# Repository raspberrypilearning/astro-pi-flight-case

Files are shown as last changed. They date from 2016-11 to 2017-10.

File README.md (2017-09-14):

# 3D-Printed Astro Pi flight case

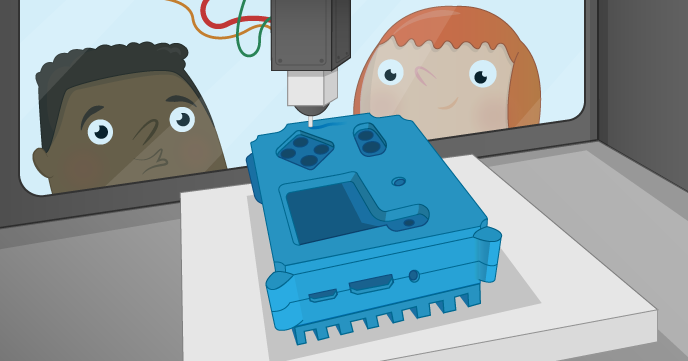
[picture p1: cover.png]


The Astro Pi flight case is one of the most desirable cases in the history of the Raspberry Pi. This resource shows you how to 3D print your own case and install the Astro Pi hardware inside it. You'll then have your very own Astro Pi flight unit, identical in almost every way to the ones on the International Space Station right now.

If you're participating in an Astro Pi competition, this is a great way to prototype and efficiently test your code in the same way as it would be used by the crew of the ISS.

## Licence

Unless otherwise specified, everything in this repository is covered by the following licence:



***3D-Printed Astro Pi Flight Case*** by the [Raspberry Pi Foundation](http://www.raspberrypi.org) is licenced under a [Creative Commons Attribution 4.0 International License](http://creativecommons.org/licenses/by-sa/4.0/).

Based on a work at https://github.com/raspberrypilearning/astro-pi-flight-case

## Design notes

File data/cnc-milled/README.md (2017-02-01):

# Flight CAD

5 axis CNC mill required.

These CAD files were used to manufacture the flight units flown to the ISS by the Astro Pi mission.

STEP, Parasoilid and STL formats with some PDF diagrams for convenience.

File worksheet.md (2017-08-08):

# 3D-printed Astro Pi flight case

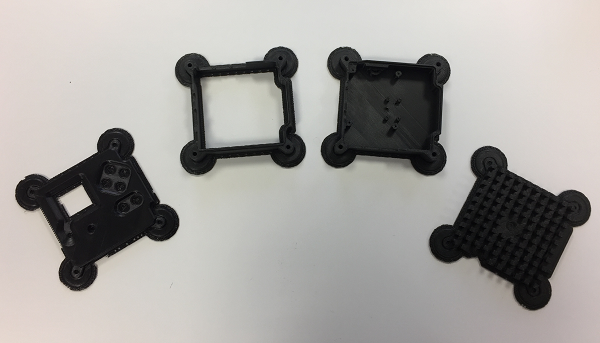
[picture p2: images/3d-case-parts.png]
3D prints of case


The Astro Pi flight case is one of the most desirable cases in the history of the Raspberry Pi. In this resource, you will learn how to 3D print your own case and install the Astro Pi hardware inside it. You'll then have your very own Astro Pi flight unit, identical in almost every way to the ones on the International Space Station right now.

If you're participating in an Astro Pi competition, this is a great way to prototype and efficiently test your code in the same way as it would be used by the crew of the ISS.

You can follow the video tutorial of this resource [here](https://www.youtube.com/embed/zmJOA6WzfZw).

<iframe width="560" height="315" src="https://www.youtube.com/embed/zmJOA6WzfZw" frameborder="0" allowfullscreen></iframe>

## Get access to a 3D printer

First and foremost, you'll need access to a 3D printer to do this. Many schools now have their own, but if your school doesn't then you may be able to find one at your local [hackspace](http://www.hackspace.org.uk/wiki/Main_Page). You can also find local 3D printing services through the [3D Hubs](https://www.3dhubs.com/) website.

## Get the 3D files

The 3D files are in [STL](https://en.wikipedia.org/wiki/STL_%28file_format%29) format, which is widely used in 3D printing all over the world. The software for your 3D printer will have no problem loading them. Import using metric millimetres (mm) and no scale adjustments will be required.

You can choose between printing using the standard STL file or the anti-warping STL file for each component. The anti-warping files add extra scaffolding around the case print to prevent the part becoming warped as it cools.

Print **one** file from each section:

**Part 1 - Heat sink**

* [Heat sink](https://github.com/raspberrypilearning/astro-pi-flight-case/raw/master/data/3d-printed/STL/Astro_Pi_Heat_Sink.stl) or [Anti-warp heat sink](https://github.com/raspberrypilearning/astro-pi-flight-case/raw/master/data/3d-printed/STL/anti-warping/Astro_Pi_Heat_Sink_warp.stl)

**Part 2 - Base**

* [Base for Model B+ or Pi 2](https://github.com/raspberrypilearning/astro-pi-flight-case/raw/master/data/3d-printed/STL/Astro_Pi_Base_Pi1_or_2.stl) or [Anti-warp base for Model B+ or Pi 2](https://github.com/raspberrypilearning/astro-pi-flight-case/raw/master/data/3d-printed/STL/anti-warping/Astro_Pi_Base_Pi1_or_2_warp.stl)
* [Base for Pi 3](https://github.com/raspberrypilearning/astro-pi-flight-case/raw/master/data/3d-printed/STL/Astro_Pi_Base_Pi3.stl) or [Anti-warp base for Pi 3](https://github.com/raspberrypilearning/astro-pi-flight-case/raw/master/data/3d-printed/STL/anti-warping/Astro_Pi_Base_Pi3_warp.stl)

**Part 3 - Middle**

* [Middle](https://github.com/raspberrypilearning/astro-pi-flight-case/raw/master/data/3d-printed/STL/Astro_Pi_Middle.stl) or [Anti-warp middle](https://github.com/raspberrypilearning/astro-pi-flight-case/raw/master/data/3d-printed/STL/anti-warping/Astro_Pi_Middle_warp.stl)

**Part 4 - Lid**

* [Lid 10mm](https://github.com/raspberrypilearning/astro-pi-flight-case/raw/master/data/3d-printed/STL/Astro_Pi_Lid_10mm_Buttons.stl) or [Anti-warp lid 10mm](https://github.com/raspberrypilearning/astro-pi-flight-case/raw/master/data/3d-printed/STL/anti-warping/Astro_Pi_Lid_10mm_Buttons_warp.stl) - 10mm holes, for use with the APEM buttons
* [Lid 7mm](https://github.com/raspberrypilearning/astro-pi-flight-case/raw/master/data/3d-printed/STL/Astro_Pi_Lid_7mm_Buttons.stl) or [Anti-warp lid 7mm](https://github.com/raspberrypilearning/astro-pi-flight-case/raw/master/data/3d-printed/STL/anti-warping/Astro_Pi_Lid_7mm_Buttons_warp.stl) - 7mm holes, for use with the buttons from the *components kit bag* in the ESA branded Astro Pi kits. Sold separately by [CPC](http://cpc.farnell.com/ucreate/uc-apk-comp1/astro-pi-component-kit-budget/dp/SC14158).
* [Lid 3mm](https://github.com/raspberrypilearning/astro-pi-flight-case/raw/master/data/3d-printed/STL/Astro_Pi_Lid_3mm_Pilot_Holes.stl) or [Anti-warp lid 3mm](https://github.com/raspberrypilearning/astro-pi-flight-case/raw/master/data/3d-printed/STL/anti-warping/Astro_Pi_Lid_3mm_Pilot_Holes_warp.stl) - 3mm pilot holes, for drilling to fit any button size

**Part 5 - Joystick cap**

Note that this joystick cap may need some slight adjustments due to the nozzle size and layer height of your printer. If you have difficulty with fitting it onto the stump of the Sense HAT joystick then try using a layer height of 0.1 mm as opposed to 0.15 mm.

* [Joystick](https://github.com/raspberrypilearning/astro-pi-flight-case/raw/master/data/3d-printed/STL/Astro_Pi_Joystick.stl)

The 3D files don't exactly match those used to make the aluminium flight cases on the International Space Station. They have been modified to make them compatible with 3D printers, so that most people who attempt this will achieve success without difficulty.

Most importantly, the case has been sliced into four parts. This has been done to minimise the amount of rafting and scaffolding that needs to be printed along with the model. It also reduces the amount of time you spend cleaning up the final prints.

## Safety first

**It is important that you observe the correct safety procedures specified in the data sheet for your specific 3D printer.**

Potential hazards include:

- Hot surfaces and thermoplastics (print head block and lamp)
- Ultraviolet radiation (lamp)
- High voltage (lamp connector, electric outlet)
- Moving parts (printing assembly)

## Print each part

The 3D printer we used for the black parts shown was an [Up Plus 2](https://www.3dhubs.com/3d-printers/up-plus-2), called the Afinia H480 in the US, using ABS filament. Because there are so many different types of 3D printer, we cannot possibly provide instructions for them all. We can only provide rough guidance here and you'll need to figure out the rest on your own.

Here are some top tips though:

- Spend some time making sure your printer is properly calibrated and tested
- [PLA](https://en.wikipedia.org/wiki/Polylactic_acid) is more reliable and nicer to print with than [ABS](https://en.wikipedia.org/wiki/Acrylonitrile_butadiene_styrene)
- A [Zebra](http://www.printinz.com/zebra-plates/) or [Buildtak](http://www.buildtak.eu/) plate provides a great surface to print on without any extra adhesive being required
- If your printer has a Z probe sensor, this will help compensate for the bed not being perfectly level; ensure it's working correctly if you have one

To get a nice finish we recommend you print on a high detail setting; this is usually a number specified in [microns](https://en.wikipedia.org/wiki/Micrometre) in the 3D printer software. The lower this number is, the more precise the model will be. Please also be aware that precise prints take longer and, for these models, each piece can take up to **four** hours to complete. Make sure you have enough filament.

The STL files should have the models like this by default, but please make sure you print in the orientations shown below in order to minimise scaffolding and rafting.

### Heat sink

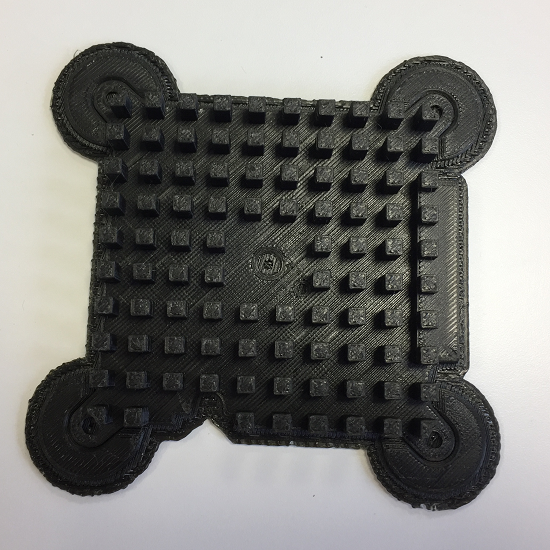
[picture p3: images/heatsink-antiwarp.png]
Anti warp heat sink raw print


### Base

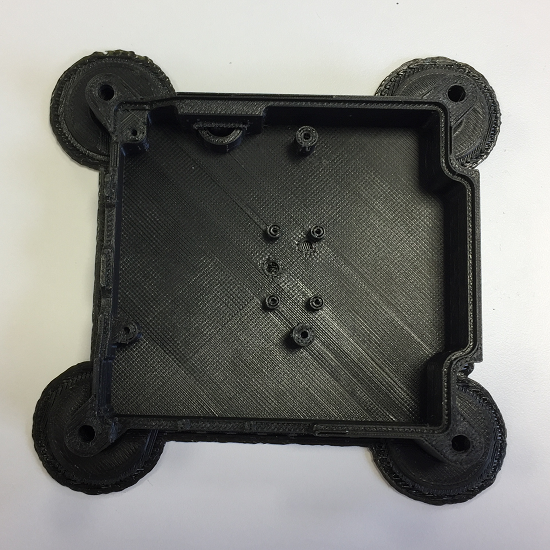
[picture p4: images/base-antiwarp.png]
Anti warp base raw print


### Middle

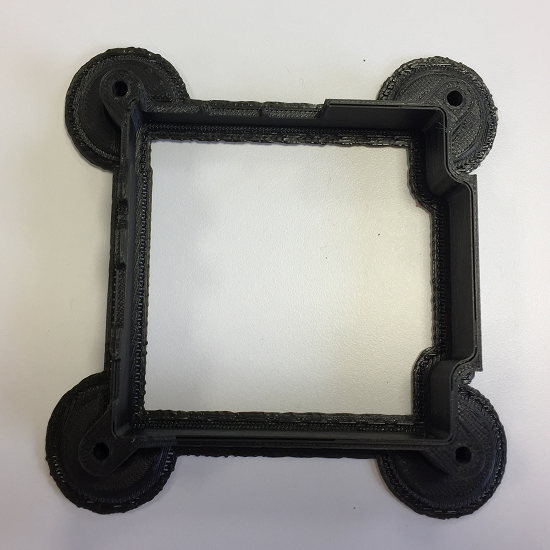
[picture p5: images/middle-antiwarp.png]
Anti warp middle raw print


### Lid

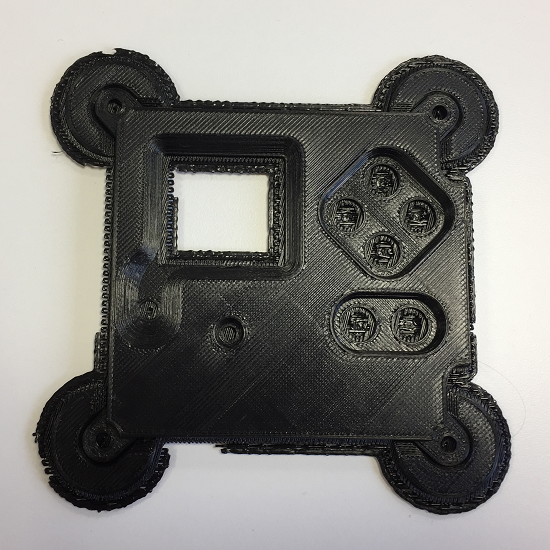
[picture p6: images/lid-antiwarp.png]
Anti warp lid raw print


## Remove the scaffolding

In order to keep the model structurally sound while printing, your 3D printer will create what's called scaffolding and rafting to prevent the hot thermoplastics from bending or sagging. Leave the print to cool right down to room temperature before you touch it.

### Heat sink

You should be able to remove the scaffolding on the heat sink using just your hands; this part may bend slightly, so don't be too rough while you are removing the unwanted material.

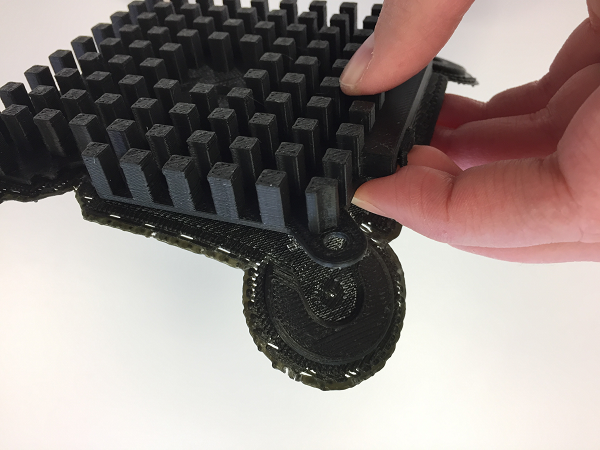
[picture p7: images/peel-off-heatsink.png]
Peel off the heat sink scaffolding


You may choose to not print this part because it's not essential to the rest of the case, and because it's made of plastic it **will not** work as a heat sink. We've included it, though, so that you can achieve the iconic look and feel of the Astro Pi flight case.

### Base

The base scaffolding should come away easily as with the heat sink.

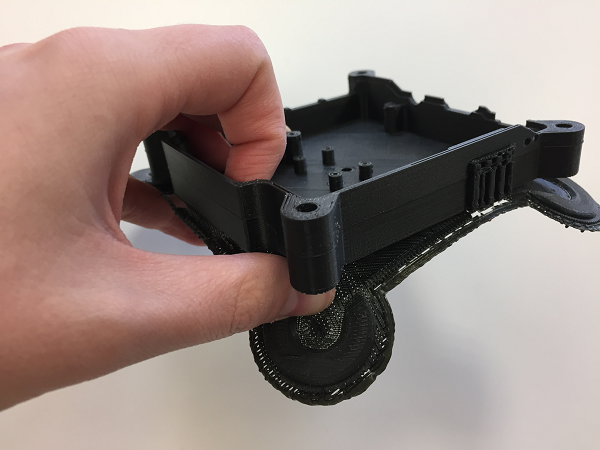
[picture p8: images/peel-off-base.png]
Peel off the base scaffolding


If the scaffolding breaks off unintentionally, carefully prise up the remaining scaffolding using a scalpel and then continue peeling it off with your fingers.

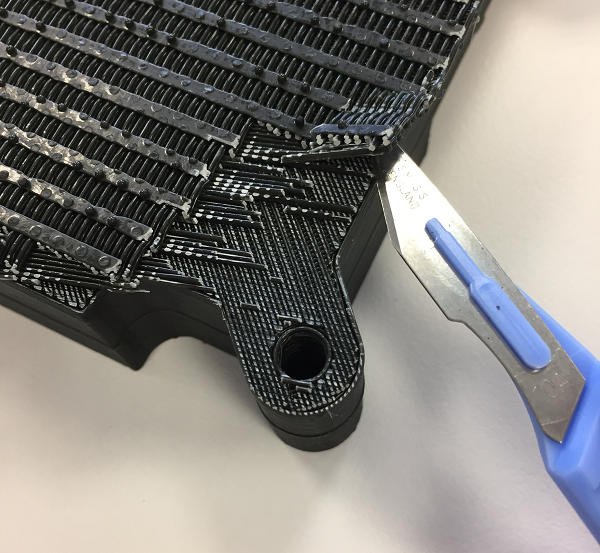
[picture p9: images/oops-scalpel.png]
If the scaffolding breaks


Don't worry if you scuff the surface with the scalpel as the rough side of the print will not be visible when the case is assembled.

Don't forget to clear the material around the SD card slot; this can easily be done with pliers.

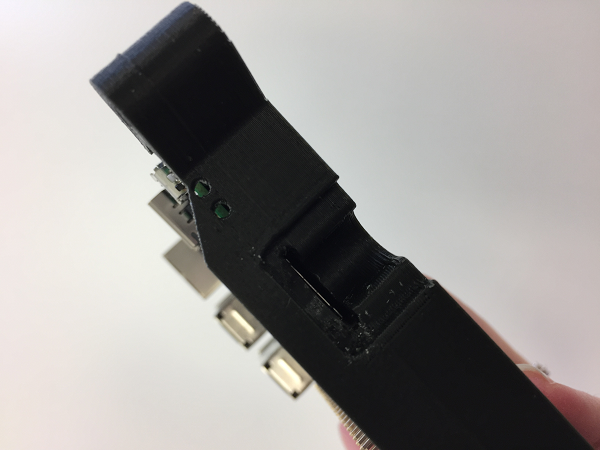
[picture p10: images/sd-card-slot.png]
Clear the SD card slot


### Middle

Again, the scaffolding should come away easily by peeling it with your fingers.

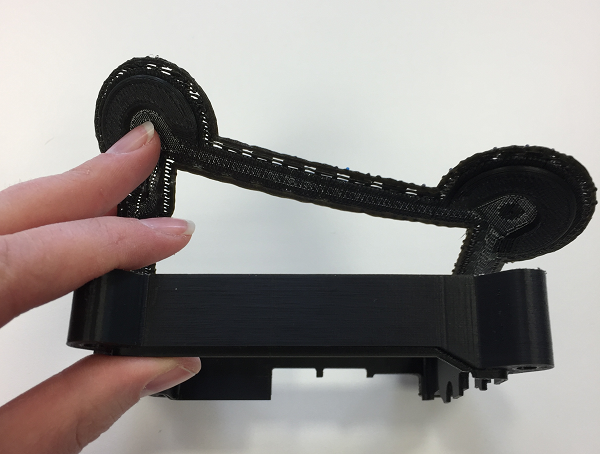
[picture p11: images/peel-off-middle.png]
Peel off the middle scaffolding


### Lid

Peel off the bottom layer of scaffolding as before.

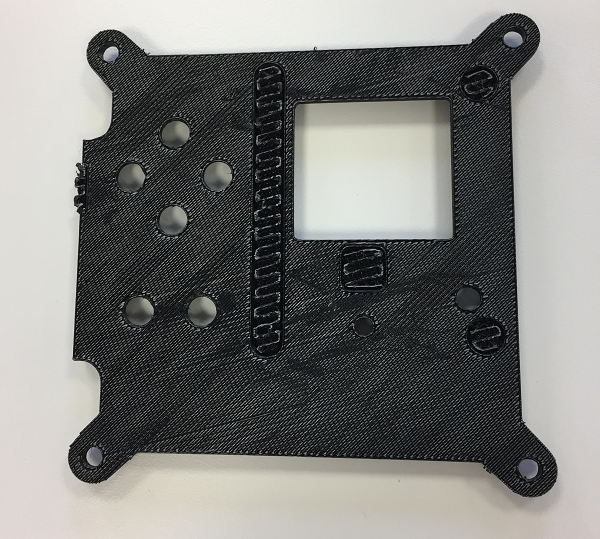
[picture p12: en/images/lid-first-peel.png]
When you first peel off the lid


However, there are a few sunken holes on the underside that must also be cleared of material. These are present to prevent the lid from striking the Raspberry Pi hardware when it is installed in the case. You'll need a scalpel or craft knife to dig into it.

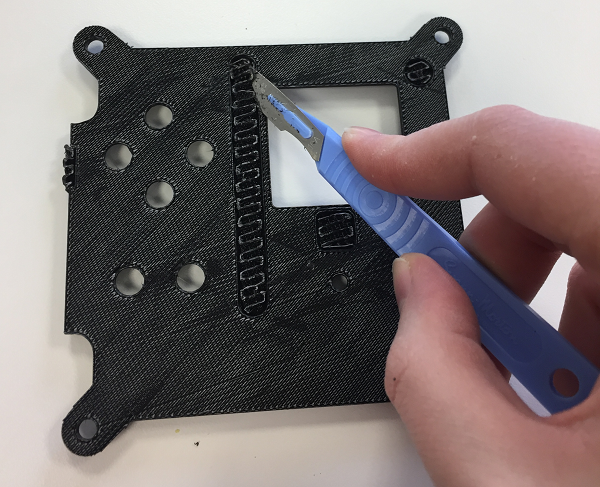
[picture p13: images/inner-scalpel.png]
Use a scalpel to lift the scaffold


Once you've managed to lift some of it, use a small pair of pliers to remove the rest of the material. The areas marked with a red star below need the same treatment.

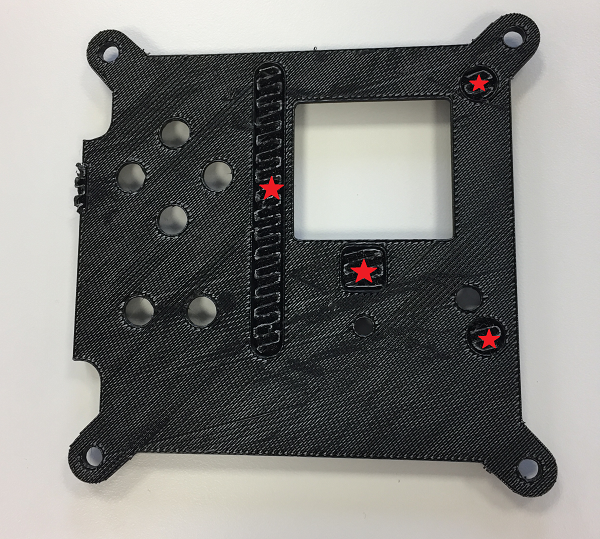
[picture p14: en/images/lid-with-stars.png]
Stars show which bits need to be removed


When you're done it should look like this:

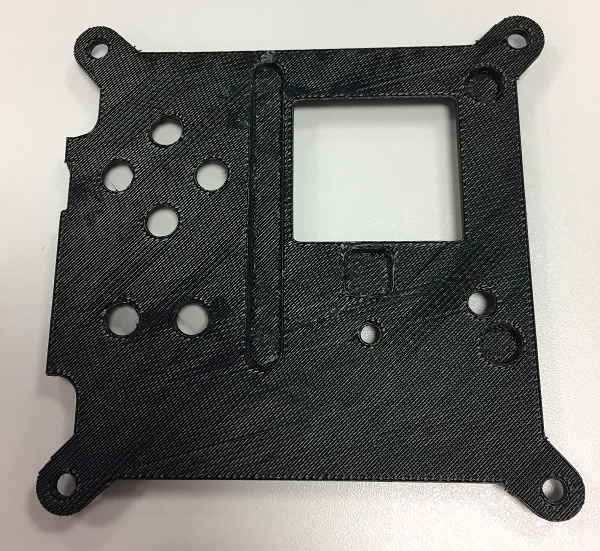
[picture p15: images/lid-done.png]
Cleaned up lid


## Do a fit check

Before proceeding, put all the pieces together to check that they fit correctly. The lipped edge between the base and middle pieces is of most concern to you here. The heat sink and lid just need to line up.

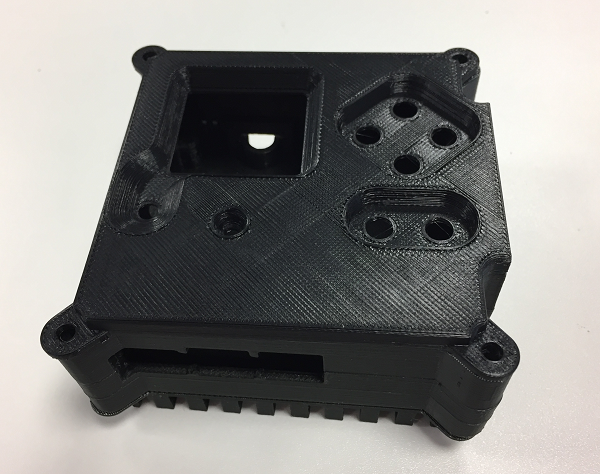
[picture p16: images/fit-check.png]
Fit the case together


Don't worry about any imperfections or residue from the scaffolding at this stage; you can tidy this up later with sandpaper.

## Checklist

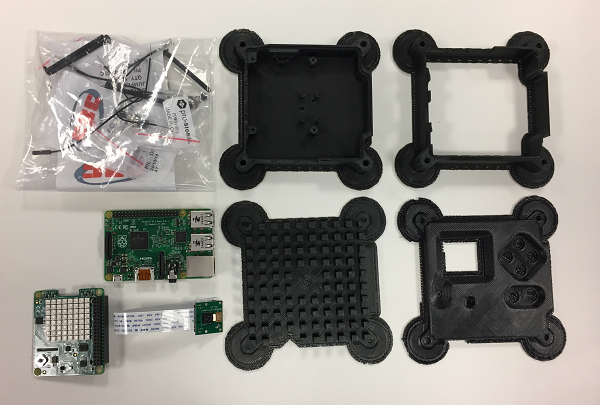
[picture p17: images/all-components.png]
All required components


Alongside your 3D-printed parts, check that you have all of the other parts required before you start:

Part|Quantity|Info|Purpose
---|---|---|---
Raspberry Pi|1|B+, Pi 2, or Pi 3|Main computer
Camera Module|1|Normal or Pi NoIR|Main camera
Sense HAT|1|&nbsp;|Main sensors

If you're planning to build a full Astro Pi flight unit, you can purchase a [kit containing the required components](http://cpc.farnell.com/ucreate/uc-apk-comp1/astro-pi-component-kit-budget/dp/SC14158) from CPC.

Part|Quantity|Info|Purpose
---|---|---|---
female-to-female jumper wires|10|Two each of red, yellow, blue, green, black|Connecting the buttons
Extended 26-way pin header|1|&nbsp;|Goes onto the GPIO pins to hold the Sense HAT at the correct height
Insulation boot|15|&nbsp;|Insulates button wiring
Friction fit crimp|15||Crimping wires together
M2 cross-head screw|4|Black 4 mm|Fixes Camera Module to base
M2.5 cross-head screw|4|Silver 6 mm|Fixes the top of the Sense HAT to the stand offs below
M2.5 washer|4|&nbsp;|Holds the Sense HAT at the correct height
M2.5 nut|4|&nbsp;|Holds the Sense HAT at the correct height
M4 hex nut|4|&nbsp;|Used in the corner bolt enclosures to hold the case together
M4 bolt|4|50 mm|Used in the corner bolt enclosures to hold the case together
M2.5 male-to-female stand off|4|11 mm|Holds the Sense HAT at the correct height
M2.5 male-to-female stand off|4|8 mm|Holds the Sense HAT at the correct height
Tactile push-buttons|6|&nbsp;|Function buttons
Length of black wire|1|&nbsp;|To cut up for push-button wiring

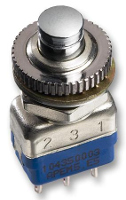
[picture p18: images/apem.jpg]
Astro Pi actual button


The kit already contains buttons, but if you want to buy the exact buttons used in the Astro Pi flight unit, the details are below. At about £9 each they are expensive, because they're designed to survive an enormous number of clicks before wearing out, which is necessary for a seven-year space mission.

- Manufacturer: APEM
- Manufacturer Part No: 104350003

You're also going to need the following tools:

- Small cross-head screwdriver
- Small pair of pliers
- Craft knife or scalpel
- Sandpaper
- Tape
- Wire strippers
- Wire cutters

## Continue to install the hardware

- [Install the hardware](worksheet2.md)

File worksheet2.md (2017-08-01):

# 3D printed Astro Pi flight case

- [Back to 3D printing and setup](worksheet.md)

When you're happy with the 3D-printed parts you can proceed with installing the hardware.

## Install the camera

Getting the camera into the case can be a little tricky but here is how we did it for the flight units. Firstly, lift the two tabs on either side of the Camera Module to disconnect the ribbon cable from the camera. Then fold the ribbon. These folds allow the camera cable to come up the side of the Raspberry Pi with enough flex to insert into the CSI camera port (see further down).

1. Lay the ribbon out with the writing face up and the visible connectors on the left. At 1cm along the ribbon, fold the ribbon downwards.

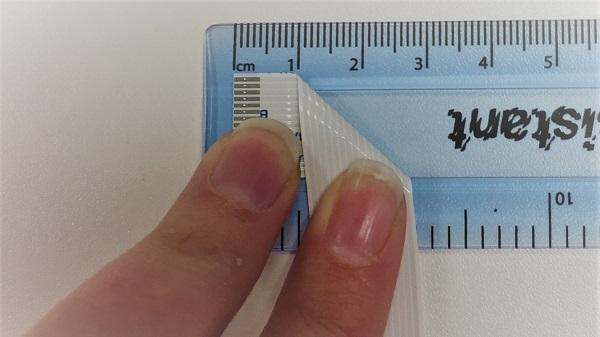
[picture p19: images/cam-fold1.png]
Fold down at 1cm
  

2. Now measure 4cm from the top of the ribbon and fold the ribbon to the right.

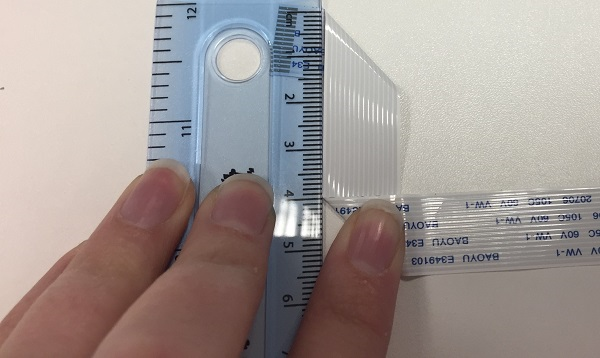
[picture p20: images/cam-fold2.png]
Fold 4cm right
  

3. Finally, measuring 4cm from the bottom-left corner, fold the ribbon upwards.

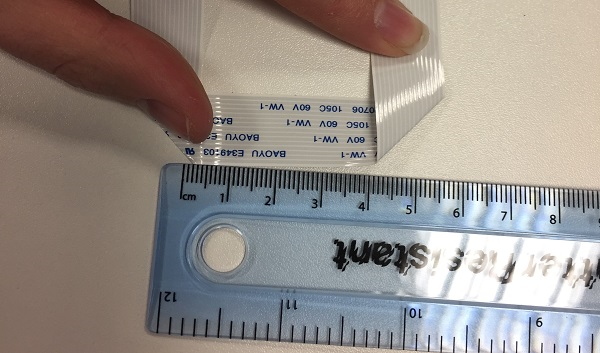
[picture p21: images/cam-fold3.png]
Fold 1cm
  

4. Tape the ribbon on the bottom to prevent it from unfurling. We have used kapton tape but any kind of tape will work fine.

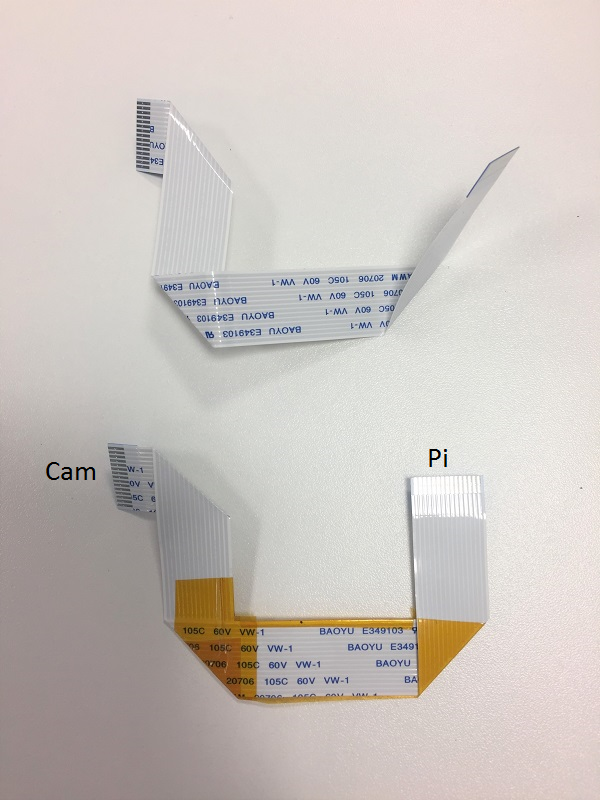
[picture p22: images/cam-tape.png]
Camera with tape
  

You don't need to get this perfect for it to work, but try to get it as close as possible.

Reconnect the **Cam** end of the ribbon cable to the Camera Module. Make sure that the tin connectors are facing the front and the blue tab is on the back.

Before proceeding, line the Camera Module up with the support pillar pilot holes and have a look through the aperture in the base to check the alignment of the lens. The lens block of the Camera Module is actually glued in position at the factory, and therefore its alignment can vary slightly from camera to camera. If you find you've got an alignment issue, you should be able to manipulate the lens block between finger and thumb before you install it into the case permanently.

When you're happy, use the small black M2 cross-head screws to install the Camera Module. The screws will cut their own thread in the support pillar pilot holes, but after a few turns you'll probably need a small screwdriver to continue.

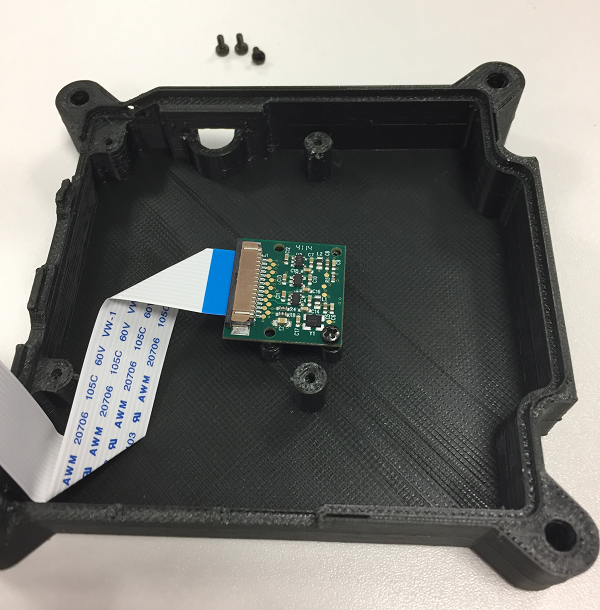
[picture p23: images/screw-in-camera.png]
Screw in the camera


Stop turning as soon as the head of the screw touches the Camera Module; if you tighten the screw too much it can cause the support pillar to split horizontally along the grain of the print. Furthermore, try to avoid removing and re-threading the screws as this will cut a new thread and, if done repeatedly, will erode the inside of the support pillar so that the screws will not hold.

## Install the Raspberry Pi

Firstly, ensure there's no residual scaffolding material around the SD card slot or LED holes that might prevent the Raspberry Pi from lining up with the mounting pillars. Once you're happy, line the Raspberry Pi up and do a fit check. Verify that it doesn't touch the Camera Module below it. Don't insert the camera ribbon cable just yet, as this will make the next job awkward.

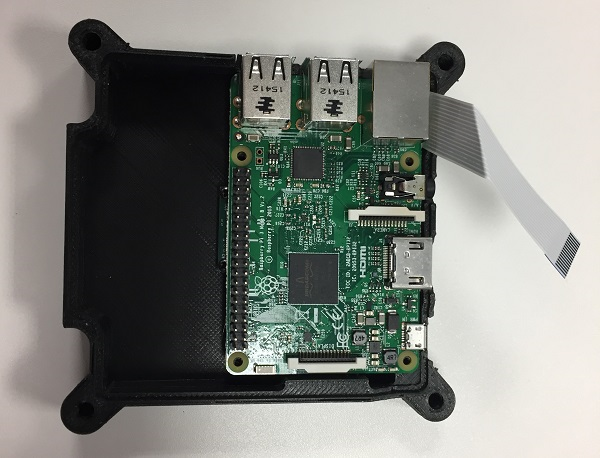
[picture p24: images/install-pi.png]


Next, screw the M2.5 11mm stand offs into each corner of the Pi. With some light finger pressure they will cut their own thread in the support pillar pilot holes. After a few turns you'll need to use a small pair of pliers to continue turning them. It's possible to get these to go in at a slight angle, which can lead to alignment issues with the Sense HAT later on, so do your best to make sure they go into the support pillars as straight as possible. Be careful while you do this and, again, stop turning as soon as the stand off touches the Raspberry Pi to avoid splitting the pillars horizontally along the grain of the print.

If you are having trouble screwing in the stand offs, screw one of the silver M2.5 cross head screws into the stand off, then use the screw head to screw the stand off into the case. Once the stand off is in place, don't forget to remove the screw.

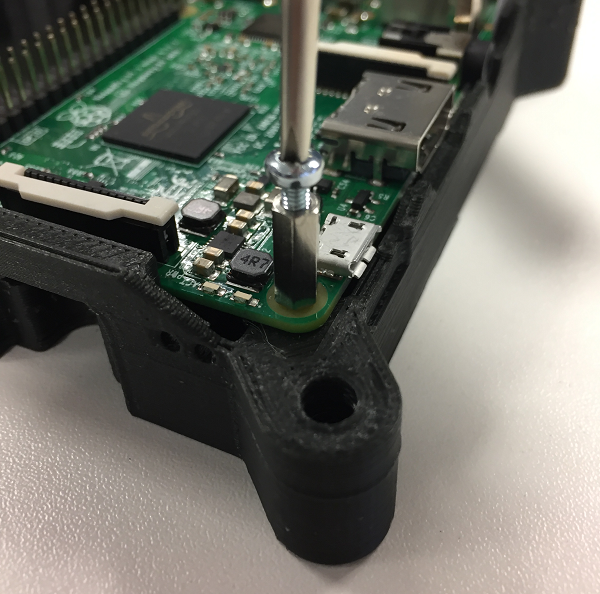
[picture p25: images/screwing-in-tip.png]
Use a screw to help you


You can now insert the camera ribbon cable into the CSI port of the Raspberry Pi. Try to make sure the tin connectors are all level to ensure a good connection.

## Install stand offs for the Sense HAT

This is where we're going to deviate from what's inside the Astro Pi flight unit. The flight units have another circuit board in between the Raspberry Pi and Sense HAT which holds a real-time clock, an oscillator crystal, and a backup battery. This RTC board also has some pins that the six push-buttons connect to. Unfortunately, this is not available to the public.

Our goal was to keep the 3D-printed flight case as faithful to the original as possible, so the decision was taken to not alter it to accommodate the absence of this board. It may be possible for us to release the Gerber files for it in the future so that people can make their own. We're going to use hex nuts of the same depth as the RTC board to compensate for its absence.

Add the extended 23-way pin header to the Raspberry Pi GPIO pins, at the furthest end from the USB ports. Then, take an 8mm M2.5 stand off and put a hex nut onto its thread before screwing it into the hole of the 11mm stand off, as shown below. Do the same for the remaining three stand offs.

Add standoffs

WARNING|&nbsp;
---|---
WiFi antenna|A note for Pi 3 users. Using a **metal** stand off next to the wireless antenna will degrade its performance and range. The advice is to either omit this stand off from your build or to use a nylon stand off and nylon screw instead.

Do not install the Sense HAT yet as it will get in the way when you connect the GPIO pins to the buttons.

## Install the push-buttons

This section assumes you are using the buttons from the Astro Pi [components kit](http://cpc.farnell.com/ucreate/uc-apk-comp1/astro-pi-component-kit-budget/dp/SC14158) from CPC. If you are using the APEM buttons or another type of button, these may differ in their installation.

Take a button, then unscrew and remove the nut. Sometimes the nut will get stuck on the button cap, but it should come off if you wiggle it.

Remove nut from button

Keeping the washer on the thread, insert the button from the underside of the lid. Then on the top side of the lid, put the nut back on and tighten it with your fingers. Check that the connectors are aligned horizontally on the underside before tightening fully.

Insert button and screw on nut

Do the same for the remaining buttons; when you are done it should look like this:

Finished front and back

If you are using the lid with the pilot holes then you'll need to check the datasheet for your chosen button type to find the **threaded bushing diameter**. Once you know this you can select a drill bit with this diameter, plus 1mm for clearance, and proceed to drill all six holes. We recommend using a vice or G clamp to hold the lid in place while you drill. You can then install the buttons in accordance with their requirements.

## Create the button wires

Firstly, you need to prepare the button wires to be able to attach them to the buttons. In the real flight unit, we soldered the button wires on to make them more reliable, but in the kit you will find jumper wires which will do the same job. The colour of the wires is not important as they are all exactly the same inside.

Take a coloured wire and, without cutting it, remove the black plastic sheath from **one** end. You can do this by pulling it off with wire cutters or by pulling up the small tab and removing it by hand. This exposes a pin connector. 

Pass a plastic insulation boot over the pin connector, narrow end first, and slide it out of the way down the wire. Then place the connector inside a crimp. 

Crimping the wire

Alternating the angle of your pliers, squash the crimp around the wire until there is no movement whatsoever of the pin connector within the crimp. Then slide the insulation boot back up over the wire and crimp. Repeat this six times with the other coloured jumper wires to create the wires we will connect to the six buttons.

Finished wire

To avoid having six more wires connected to the Raspberry Pi as ground wires, you will create a ground loop wire which connects to all of the buttons. This technique is also used in the real flight units. 

Take the piece of black wire, which should be approximately 50cm in length. Using a ruler and wire cutters, make five 10cm lengths. For each length, use wire strippers to expose at least 1cm of bare wire on both ends, then bend the wire into a U shape.

Black wire

Now take a black jumper wire and remove the black plastic sheath from one end to expose the connector, just as you did before. Hold the connector next to the end of one of your 10cm lengths of black wire, and pass both wires through the narrow end of an insulation boot. Insert both wires together into a crimp and tighten the crimp as before.

Black wire

Connect up the four remaining lengths of black wire to create a chain, crimping together a new wire with the exposed bare end of the previous wire. You will be left with one bare wire end as in the photograph below.

Black wire

For the final end, use pliers to fold the bare wire over to make it twice as thick before putting this wire alone inside a crimp and tightening up as before. You should end up with a chain containing six crimped ends and one black plastic jumper end.

## Connecting wires to the button terminals

First, you will connect your ground loop to the buttons. Starting with the top button, take the crimped wire end furthest from the black plastic jumper lead. Slide the insulation boot down, hold the crimp between finger and thumb and push it all the way onto the button terminal. Once the crimp is firmly in place, slide the insulation boot back up. Repeat to attach one of the black ground wire connections to each of the six buttons.

Ground wire connected to buttons

Now take the coloured wires you made earlier and connect one crimped end to the spare terminal of each button, using exactly the same method.

## Connecting the buttons to the Raspberry Pi

Fit the middle section of the Astro Pi case onto the base. You should do this now as the GPIO wires will prevent it from being fitted later.

Now you are going to wire the buttons to the free GPIO pins at the bottom of the header. Turn the Astro Pi case so that the Ethernet and USB ports are at the bottom, and the GPIO pins are on the right of the Raspberry Pi.

GPIO diagram

The pins marked in red are where you will wire up the buttons, with the bottom of the diagram being the pins closest to the USB ports. 

Look at the **underside** of the lid, with the buttons on the left and the display hole on the right. Connect the coloured wire from each button to the corresponding pin below:

- Top four buttons
    - Top: GPIO 26
    - Bottom: GPIO 13
    - Left: GPIO 19
    - Right: GPIO 20
- Bottom pair of buttons
    - Left: GPIO 21
    - Right: GPIO 16

Finally, connect the ground wire to either pin 34 or 39 (labelled Ground on the GPIO diagram). 

The lid will now be a bit awkward until we finish, but try to position it gently so it is not in the way.

The picture below is of one of the flight units that went into space. On the right, you can see the base of the RTC board with the connector pins for the buttons. If you look at the button contacts on the left, you'll see we used only one black ground wire that went from button to button.

Flight unit wiring

## Install the Sense HAT

Remove the GPIO connector that comes with the Sense HAT; wiggle it from side to side and it will come off without too much force. The Sense HAT can then be inserted onto the extended header. Note that these pins should not protrude through the top of the Sense HAT. If they do, then the height is not correct.

Remove the header from the Sense HAT

Finally, use the M2.5 cross-head screws to secure the Sense HAT to the stand offs below.

All buttons connected

## Assemble the case

Once you're happy that the internals of the case are complete, you can proceed to the final assembly stage. 

Take the lid and gently tuck the wires into the space on the right of the Pi as neatly as you can. Place the lid on top of the case and align the heat sink on the bottom.

Take the black M4 threaded bolts and insert one through each of the holes in the corners of the case. Inserting all four bolts at this stage will help to line everything up and make it easier to secure the case with the nuts.

Take one of the large hex nuts and with your index finger place it against the bottom of the bolt. Push the bolt back up so that the nut is then flush with the bottom of the case, and turn the head of the nut with your finger and thumb so that it catches the bolt thread. Tighten the nut with your fingers only. 

Hold the bolt

Once all four nuts are in place you can do a final tighten with a screwdriver.

Your Astro Pi is almost complete; the last thing to do is install your 3D-printed joystick cap by pressing it onto the joystick. For this, the real flight units use a TrackPoint cap from a Lenovo ThinkPad laptop!

Install joystick

## Test the buttons

Once you have assembled the Astro Pi, start it up with a monitor, keyboard, and mouse connected.

If you have the ESA-branded Astro Pi kit, when you turn the Astro Pi on, the rainbow pattern on the LED matrix should disappear after a few seconds and the push-buttons should now type letters. You can test this in the terminal by running the test program at the bottom of this section.

If you do not have the ESA-branded Astro Pi kit, when you turn the Astro Pi on, the rainbow pattern on the LED matrix will remain and the buttons will not work yet.

You will need to download some files and change a few configuration settings, so make sure your Astro Pi is online. Firstly, download the Device Tree overlay that maps the push-buttons to the corresponding keyboard keys. 

Open a terminal window and enter these commands:

```bash
cd /boot/overlays
sudo wget https://github.com/raspberrypilearning/astro-pi-flight-case/raw/master/data/dtb/astropi-keys.dtbo --no-check-certificate
```

Type `ls` and check that the file `astropi-keys.dtbo` is now showing in the list of files.

Next, we need to configure `config.txt` to load this overlay:

```bash
sudo nano /boot/config.txt
```

Go to the bottom of the file and enter the two lines below:

```bash
dtoverlay=rpi-sense
dtoverlay=astropi-keys
```

Press `Ctrl` + `O` then `Enter` to save, followed by `Ctrl` + `X` to quit.

Now reboot the Astro Pi.

```bash
sudo reboot
```

Now let's download and run a Python test program to check everything is working. The test code uses [Pygame](http://pygame.org/wiki/tutorials), so please do this on a directly connected monitor. It will not work via remote access. Open a terminal window and enter these commands:

```bash
cd ~
wget https://github.com/raspberrypilearning/astro-pi-flight-case/raw/master/data/test_code/pygame_test.py --no-check-certificate
chmod +x pygame_test.py
./pygame_test.py
```

Wiggle the joystick and press all push-buttons. If everything is working, the joystick should give a direction indication and the buttons will show the corresponding letter on the LED matrix. Press `Escape` to exit.

## What next?

We've deliberately not shown a really polished gorgeous case, because we're hoping you'll go the extra mile and blow our socks off. Please show us your cases by tweeting pictures of them to [@astro_pi](https://twitter.com/astro_pi) and [@raspberry_pi](https://twitter.com/Raspberry_Pi)!

Here are some further ideas for customising your case:

- Use metallic grey spray paint
- Use sandpaper to create the matt finish that the bead-blasted aluminium flight cases have
- Engrave decals into the case
- Use different colours of filament for each part

The STL files are released under the Creative Commons attribution [licence](http://creativecommons.org/licenses/by-sa/4.0/) so you are welcome to modify them. Please note that GitHub has a great [STL viewer](https://github.com/blog/1465-stl-file-viewing) as well as a [3D file diff](https://github.com/blog/1633-3d-file-diffs), which could be useful for tracking your changes.

By far the greatest benefit of owning a replica Astro Pi flight unit is the ability to prototype and test code that could be run on the International Space Station. Head over to the [Astro Pi website](https://astro-pi.org/) now to get involved!

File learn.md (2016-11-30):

By following this resource you will learn:

- How to 3D print the Astro Pi flight case
- How to correctly install the Astro Pi hardware inside the case
- What fixtures and fittings you need to accomplish this

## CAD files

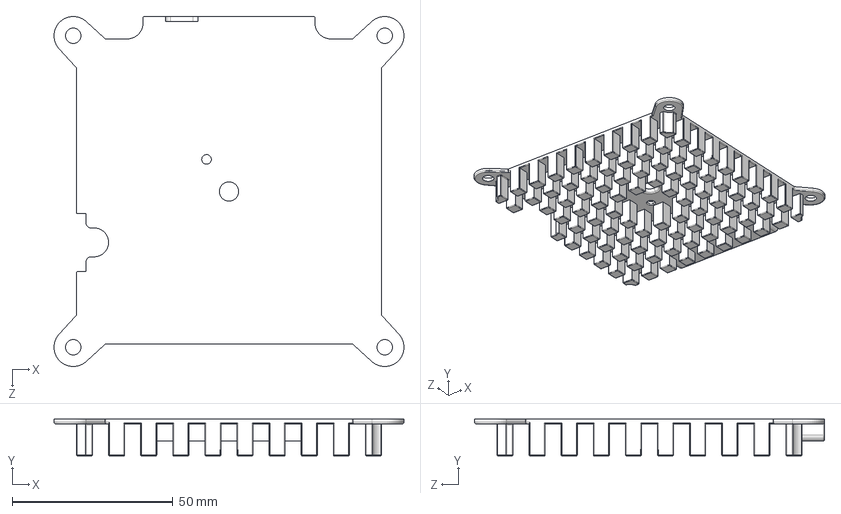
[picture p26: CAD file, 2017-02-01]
data/3d-printed/STEP/Astro_Pi_2.0_Enclosure_3D_PRINT_SECTION_1 V1.STEP
109.0 x 11.5 x 109.0 mm

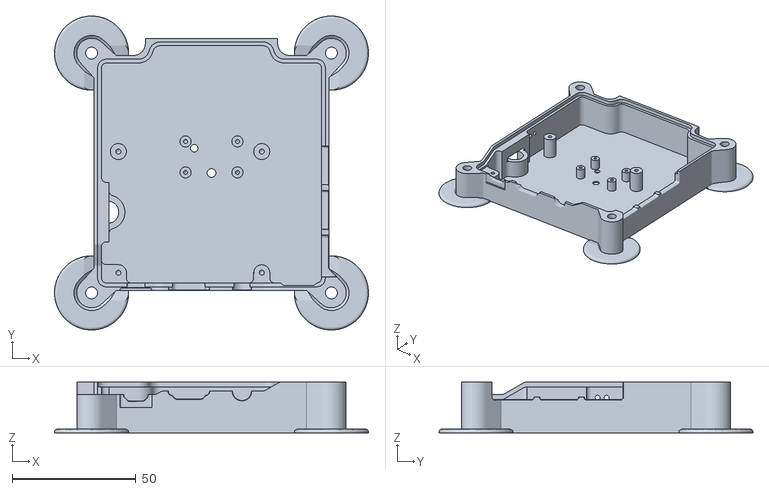
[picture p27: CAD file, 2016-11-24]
data/3d-printed/STL/anti-warping/Astro_Pi_Base_Pi1_or_2_warp.stl
127.0 x 127.0 x 20.5

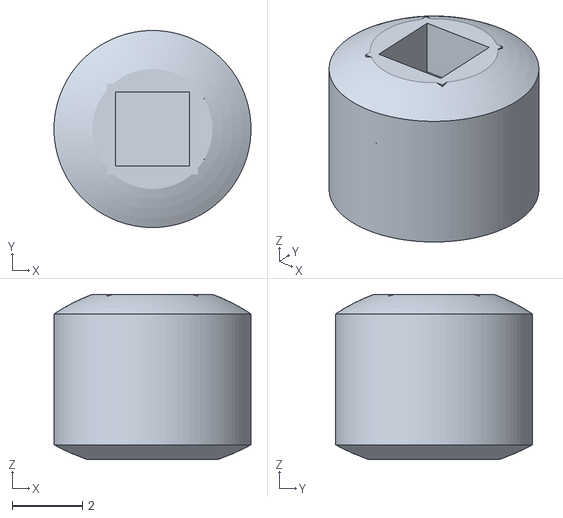
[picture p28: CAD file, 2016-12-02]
data/3d-printed/STL/Astro_Pi_Joystick.stl
5.60 x 5.60 x 4.70

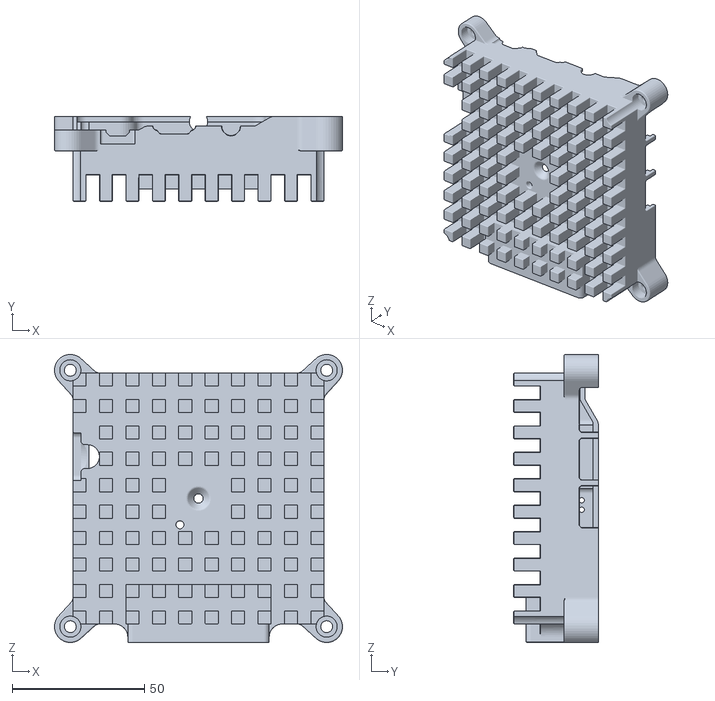
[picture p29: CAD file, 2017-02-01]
data/cnc-milled/STL/Astro_Pi_Enclosure_Body_EXPORTED_STL_050116.STL
109.0 x 32.0 x 109.0

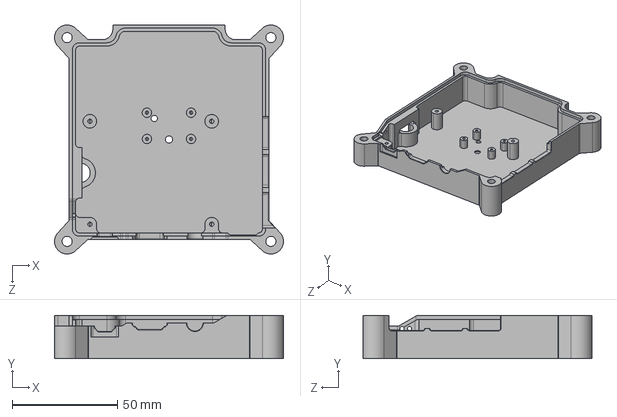
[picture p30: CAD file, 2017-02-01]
data/3d-printed/STEP/Astro_Pi_2.0_Enclosure_3D_PRINT_SECTION_2 V1a.STEP
109.0 x 20.5 x 109.0 mm

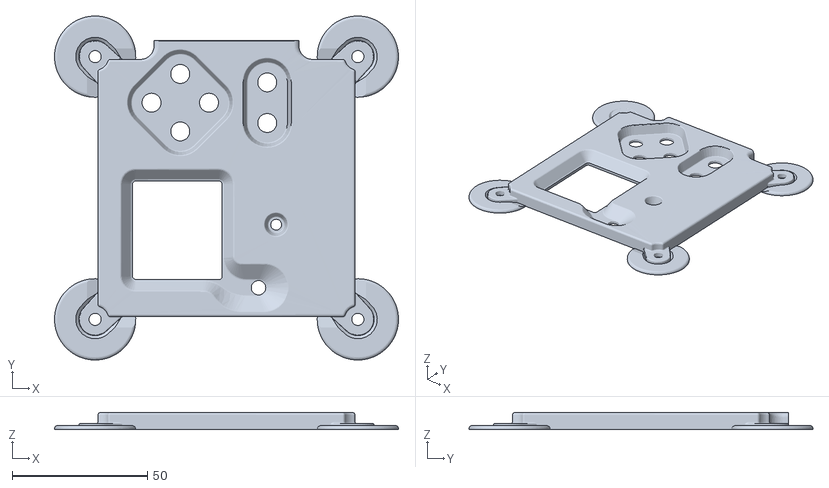
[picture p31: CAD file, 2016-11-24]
data/3d-printed/STL/anti-warping/Astro_Pi_Lid_7mm_Buttons_warp.stl
127.0 x 127.0 x 6.30

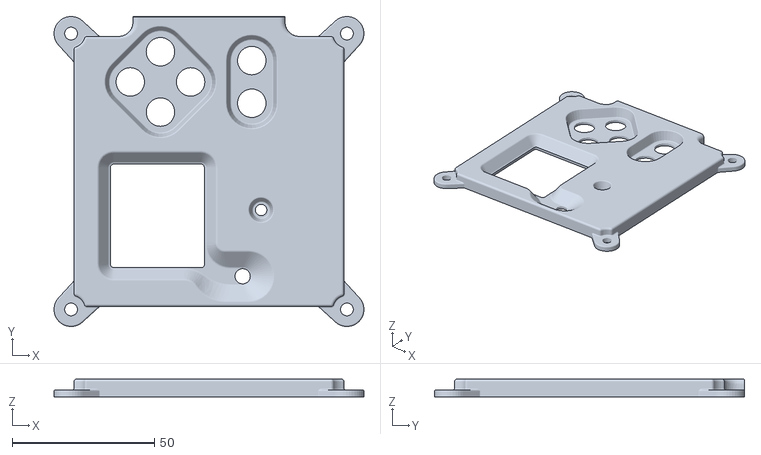
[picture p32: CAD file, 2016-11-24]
data/3d-printed/STL/Astro_Pi_Lid_10mm_Buttons.stl
109.0 x 109.0 x 6.30

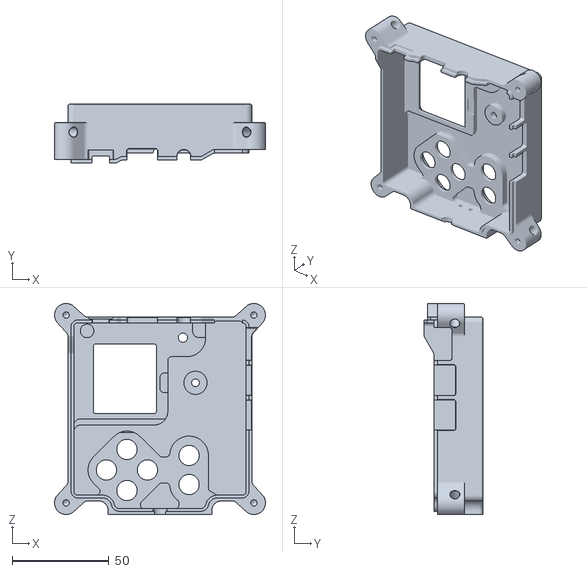
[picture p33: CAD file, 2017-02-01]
data/cnc-milled/STL/Astro_Pi_Enclosure_Lid_EXPORTED_STL_050116a.STL
109.0 x 30.4 x 109.0

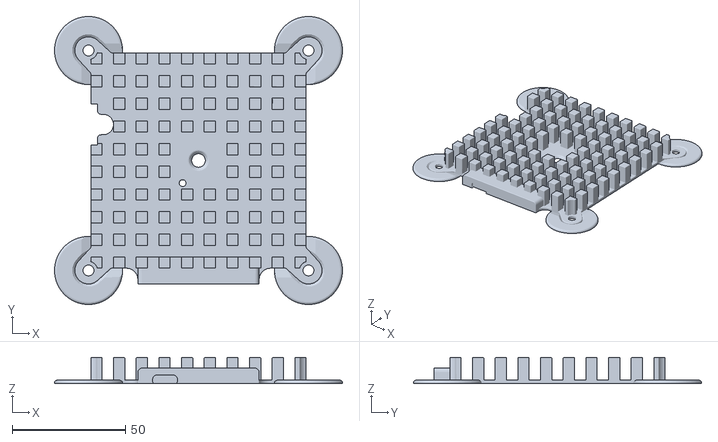
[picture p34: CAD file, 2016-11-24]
data/3d-printed/STL/anti-warping/Astro_Pi_Heat_Sink_warp.stl
127.0 x 127.0 x 11.5

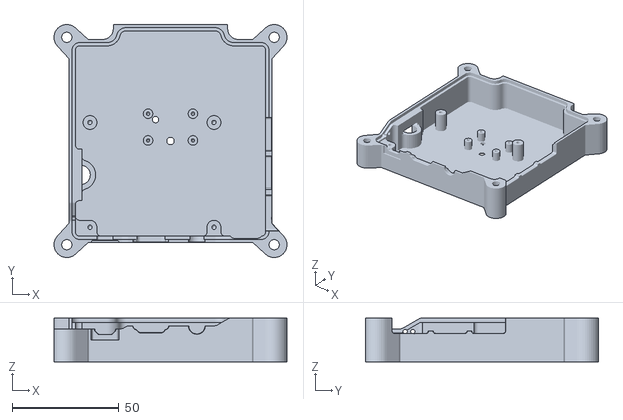
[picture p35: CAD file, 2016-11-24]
data/3d-printed/STL/Astro_Pi_Base_Pi3.stl
109.0 x 109.0 x 20.5

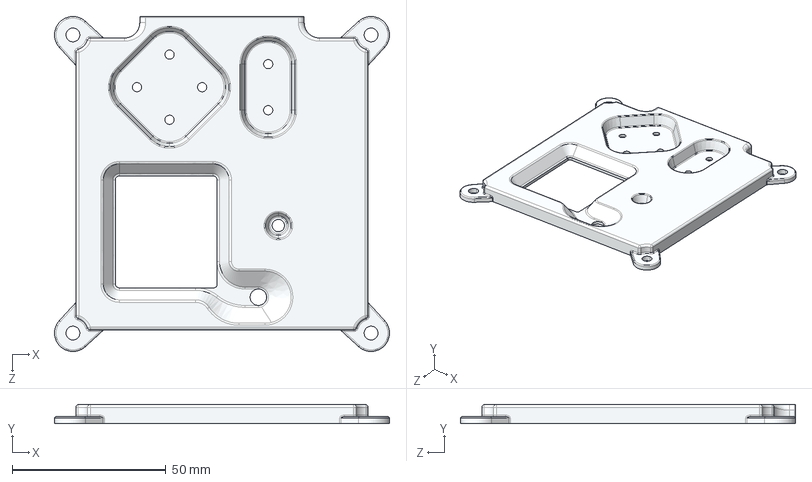
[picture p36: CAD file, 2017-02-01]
data/3d-printed/STEP/Astro_Pi_2.0_Enclosure_3D_PRINT_SECTION_4 V1a.STEP
109.0 x 6.30 x 109.0 mm

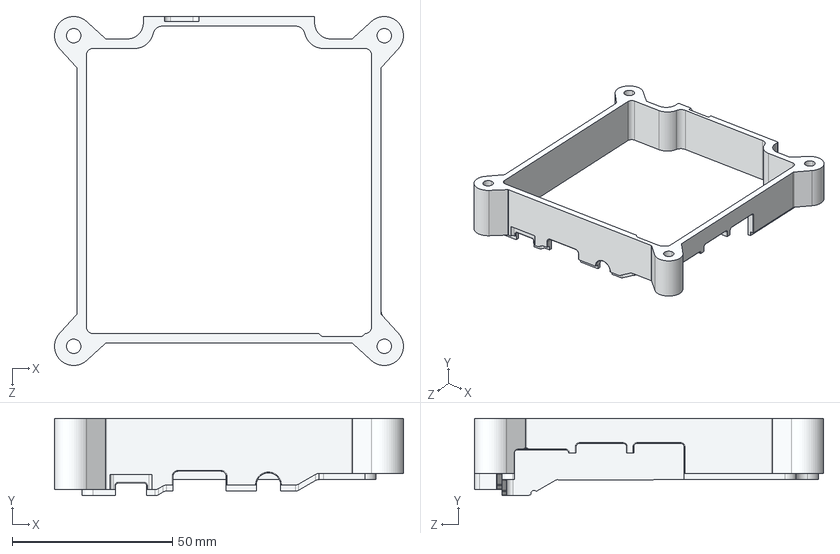
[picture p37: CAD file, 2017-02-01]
data/3d-printed/STEP/Astro_Pi_2.0_Enclosure_3D_PRINT_SECTION_3 V1.STEP
109.0 x 24.1 x 109.0 mm

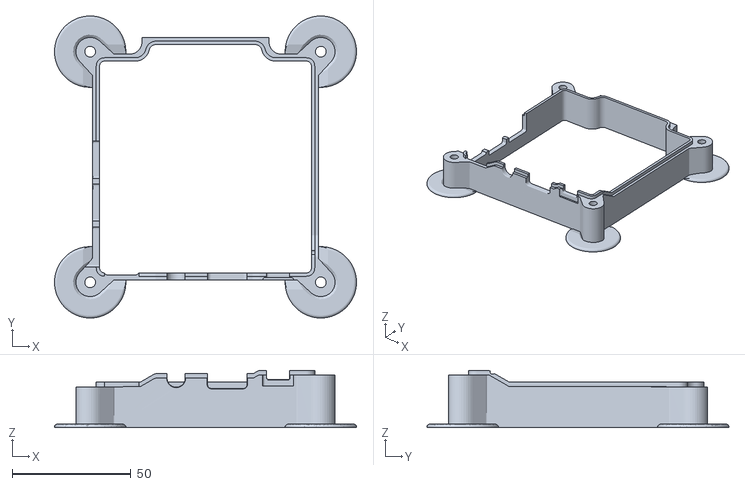
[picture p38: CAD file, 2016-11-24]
data/3d-printed/STL/anti-warping/Astro_Pi_Middle_warp.stl
127.0 x 127.0 x 24.1

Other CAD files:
data/3d-printed/STEP/Astro_Pi_2.0_Enclosure_3D_PRINT_SECTION_4 V1b.STEP
data/3d-printed/STL/anti-warping/Astro_Pi_Base_Pi3_warp.stl
data/3d-printed/STL/Astro_Pi_Lid_7mm_Buttons.stl
data/3d-printed/STL/Astro_Pi_Lid_3mm_Pilot_Holes.stl
data/3d-printed/STEP/Astro_Pi_2.0_Enclosure_3D_PRINT_SECTION_4 V1c.STEP
data/3d-printed/STEP/Astro_Pi_2.0_Enclosure_3D_PRINT_SECTION_2 V1b.STEP
data/3d-printed/STL/Astro_Pi_Base_Pi1_or_2.stl
data/3d-printed/STL/Astro_Pi_Heat_Sink.stl
data/3d-printed/STL/Astro_Pi_Middle.stl
data/3d-printed/STL/anti-warping/Astro_Pi_Lid_10mm_Buttons_warp.stl
data/3d-printed/STL/anti-warping/Astro_Pi_Lid_3mm_Pilot_Holes_warp.stl
data/3d-printed/x_t/Astro_Pi_2.0_Enclosure_3D_PRINT_SECTION_1 V1.x_t
data/3d-printed/x_t/Astro_Pi_2.0_Enclosure_3D_PRINT_SECTION_2 V1a.x_t
data/3d-printed/x_t/Astro_Pi_2.0_Enclosure_3D_PRINT_SECTION_2 V1b.x_t
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

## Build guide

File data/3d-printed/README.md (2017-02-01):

# 3D Printer Files

The files here are intended to accompany this educational [resource](https://www.raspberrypi.org/learning/astro-pi-flight-case/).

Assembly video instructions [here](https://www.youtube.com/watch?v=kY1db5cec64).

STEP and Parasoild formats also provided for you to modify the files further yourself.

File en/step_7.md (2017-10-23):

## Parts checklist

Alongside your 3D-printed parts, check that you have all of the other parts required before you start:

All required components

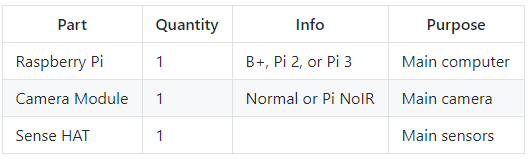
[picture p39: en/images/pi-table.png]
Pi requirements


If you're planning to build a full Astro Pi flight unit, you can purchase a [kit containing the required components](http://cpc.farnell.com/ucreate/uc-apk-comp1/astro-pi-component-kit-budget/dp/SC14158) from CPC.

--- collapse ---
---
title: Full list of kit parts
---
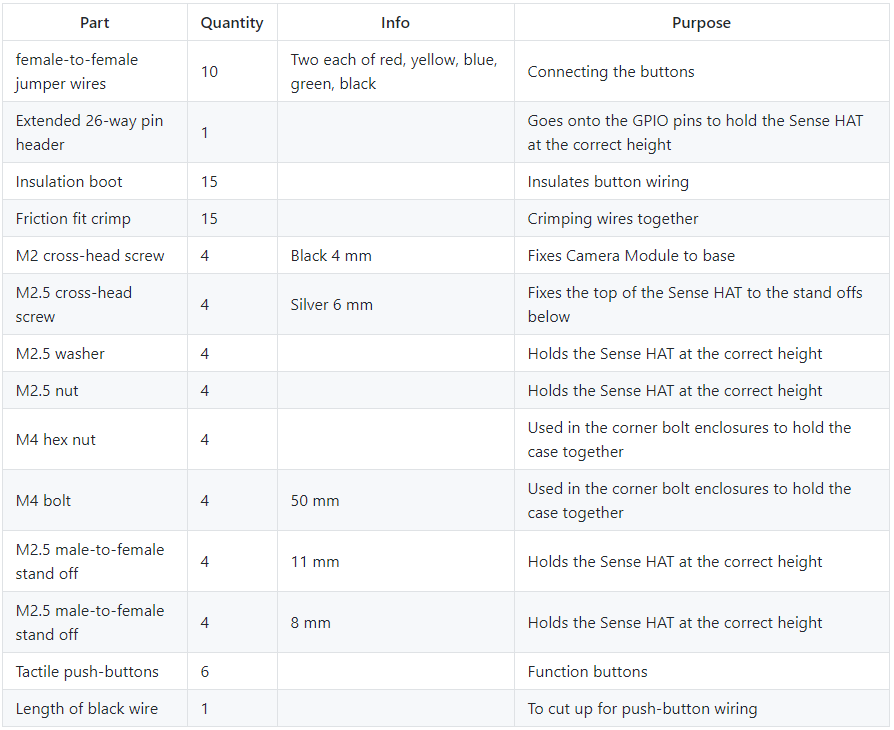
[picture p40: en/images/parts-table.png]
Parts table


--- /collapse ---

Astro Pi actual button

The kit already contains buttons, but if you want to buy the exact buttons used in the Astro Pi flight unit, the details are below. At a price of £9 each, they are expensive — that's because they're designed to survive an enormous number of clicks before wearing out, a feature which is necessary for a seven-year space mission.

- Manufacturer: APEM
- Manufacturer Part No: 104350003

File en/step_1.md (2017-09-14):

## Introduction
The Astro Pi flight case is one of the most sought-after cases in the history of the Raspberry Pi. In this resource, you will learn how to 3D print your own case and install the Astro Pi hardware inside it. You'll then have your very own Astro Pi flight unit, identical in almost every way to the ones on the International Space Station right now.

3D prints of case

If you're participating in an Astro Pi competition, this is a great way to prototype and efficiently test your code in the same way as it would be used by the crew of the ISS.

You can follow the video tutorial of this resource [here](https://www.youtube.com/embed/zmJOA6WzfZw){:target="_blank"}.

<iframe width="560" height="315" src="https://www.youtube.com/embed/zmJOA6WzfZw" frameborder="0" allowfullscreen></iframe>

### What you will make

Here is an example of how your finished 3D-printed Astro Pi flight case might look:

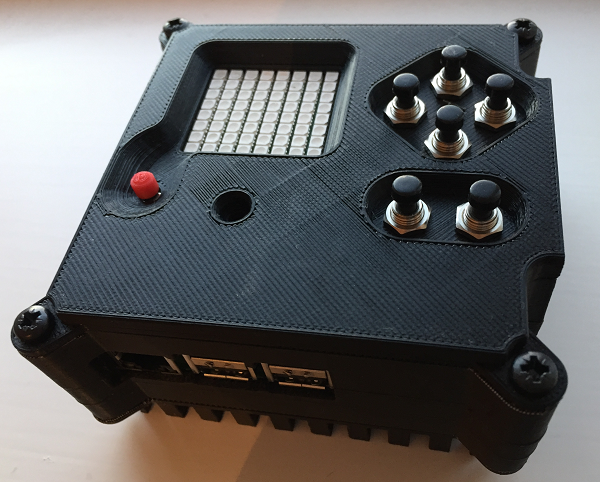
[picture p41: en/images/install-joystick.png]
Finished case


### What you will learn
By following this resource you will learn:

- How to 3D print the Astro Pi flight case
- What fixtures and fittings you need to install the Astro Pi hardware
- How to correctly install the Astro Pi hardware inside the case

This project covers elements from the following strands of the [Raspberry Pi Digital Making Curriculum](http://rpf.io/curriculum){:target="_blank"}:

+ [Use manufacturing techniques and tools to create a completed product](https://curriculum.raspberrypi.org/manufacture/developer/){:target="_blank"}

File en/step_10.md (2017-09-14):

## Install stand-offs for the Sense HAT

This is where we're going to deviate from what's inside the Astro Pi flight unit. The flight units have another circuit board in between the Raspberry Pi and Sense HAT which holds a real-time clock, an oscillator crystal, and a backup battery. This RTC board also has some pins with six connected push-buttons. Unfortunately, the board is not available to the public.

Our goal was to keep the 3D-printed flight case as faithful to the original as possible, so the decision was taken to not alter it to accommodate the absence of this board. It may be possible for us to release the Gerber files for it in the future, so that people can make their own. We're going to use hex nuts of the same depth as the RTC board to compensate for its absence.

+ Add the extended 23-way pin header to the Raspberry Pi GPIO pins, at the end away from the USB ports.

+ Then, take an 8mm M2.5 stand-off and put a hex nut onto its thread before screwing it into the hole of the 11mm stand-off, as shown below. Do the same for the remaining three stand-offs.

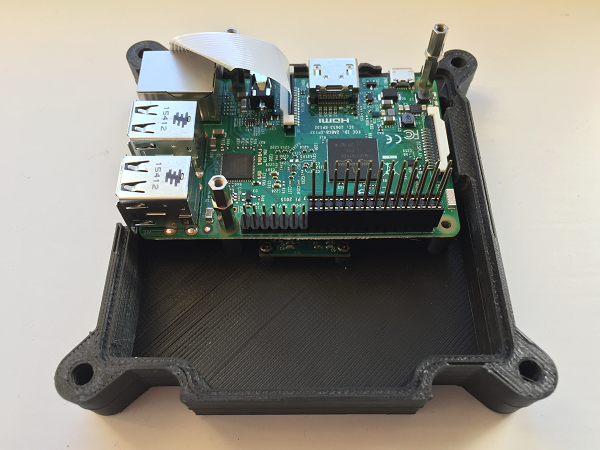
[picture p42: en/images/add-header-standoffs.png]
Add standoffs


WARNING|&nbsp;
---|---
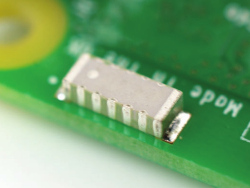
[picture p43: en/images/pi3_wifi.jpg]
WiFi antenna
|A note for Pi 3 users. Using a **metal** stand-off next to the wireless antenna will degrade its performance and range. The advice is to either omit this stand-off from your build, or to use a nylon stand-off and nylon screw instead.

+ Do not install the Sense HAT yet, as it will get in the way when you connect the GPIO pins to the buttons.

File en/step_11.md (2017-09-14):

## Install the push-buttons

This section assumes you are using the buttons from the Astro Pi [components kit](http://cpc.farnell.com/ucreate/uc-apk-comp1/astro-pi-component-kit-budget/dp/SC14158){:target="_blank"} from CPC. If you are using APEM buttons or another type of button, their installation might be different.

+ Take a button, then unscrew and remove the nut. Sometimes the nut will get stuck on the button cap, but it should come off if you wiggle it.

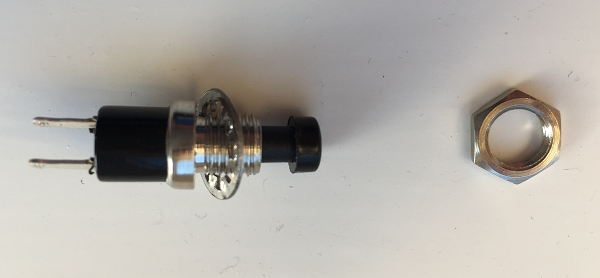
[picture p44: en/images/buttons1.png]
Remove nut from button


+ Keeping the washer on the thread, insert the button from the underside of the lid.

+ Then on the top side of the lid, put the nut back on and tighten it with your fingers. Check that the connectors are aligned horizontally on the underside before tightening fully.

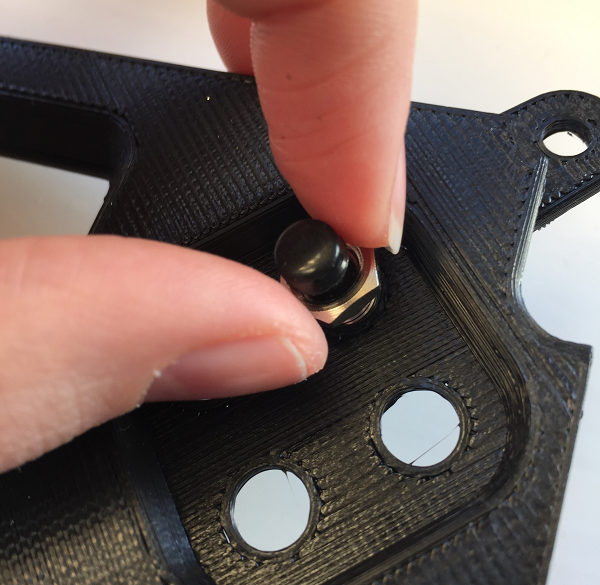
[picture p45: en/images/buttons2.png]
Insert button and screw on nut


+ Do the same for the remaining buttons; when you are done it should look like this:

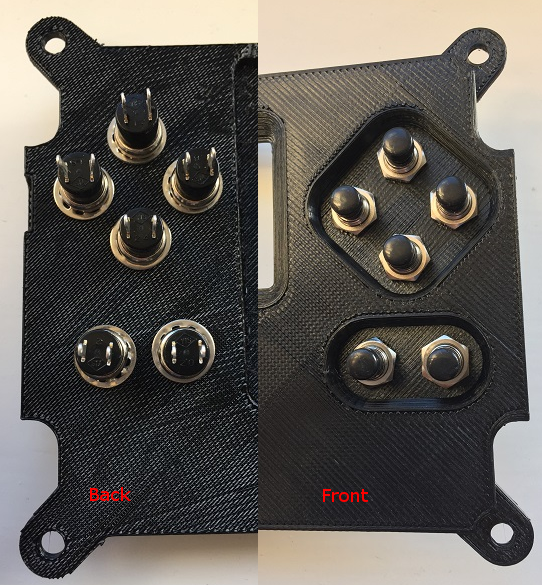
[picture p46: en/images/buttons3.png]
Finished front and back


If you are using the lid with the pilot holes, then you'll need to check the datasheet for your chosen button type to find the **threaded bushing diameter**. Then you can select a drill bit with this diameter, plus 1mm for clearance, and proceed to drill all six holes. We recommend using a vice or a G clamp to hold the lid in place while you drill. You can then install the buttons in accordance with their requirements.

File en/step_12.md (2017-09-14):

## Create the button wires

Firstly, you need to prepare the button wires to be able to attach them to the buttons. In the real flight unit, we soldered the button wires on to make them more reliable — in the kit you will find jumper wires which will do the same job. The colour of the wires is not important, as they are all exactly the same inside.

+ Take a coloured wire and, without cutting it, remove the black plastic sheath from **one** end. You can do this by pulling it off with wire cutters, or by pulling up the small tab and removing it by hand. This exposes a pin connector.

+ Pass a plastic insulation boot over the pin connector narrow end first, and slide it out of the way down the wire. Then place the connector inside a crimp.

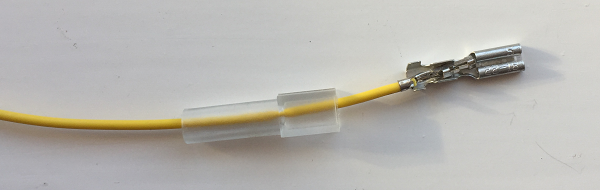
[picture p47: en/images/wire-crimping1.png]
Crimping the wire


+ Alternating the angle of your pliers, squash the crimp around the wire until there is no movement whatsoever of the pin connector within the crimp. Then slide the insulation boot back up over the wire and crimp.

+ Repeat this six times with the other coloured jumper wires to create the wires we will connect to the six buttons.

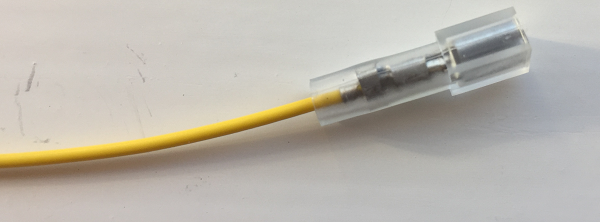
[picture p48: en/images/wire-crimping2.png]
Finished wire


Instead of connecting six more wires to the Raspberry Pi as ground wires, you will create a ground loop wire which connects to all of the buttons. This technique is also used in the real flight units.

+ Take the piece of black wire, which should be approximately 50cm in length. Using a ruler and wire cutters, make five 10cm lengths.

+ For each length, use wire strippers to expose at least 1cm of bare wire on both ends, then bend the wire into a U shape.

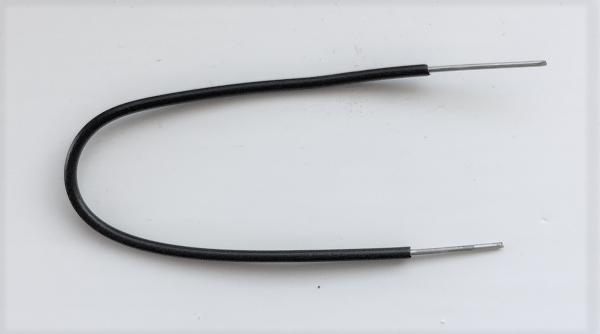
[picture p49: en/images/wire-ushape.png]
Black wire


+ Now take a black jumper wire and remove the black plastic sheath from one end to expose the connector, just as you did before.

+ Hold the connector next to the end of one of your 10cm lengths of black wire, and pass both wires through the narrow end of an insulation boot.

+ Insert both wires together into a crimp and tighten the crimp as before.

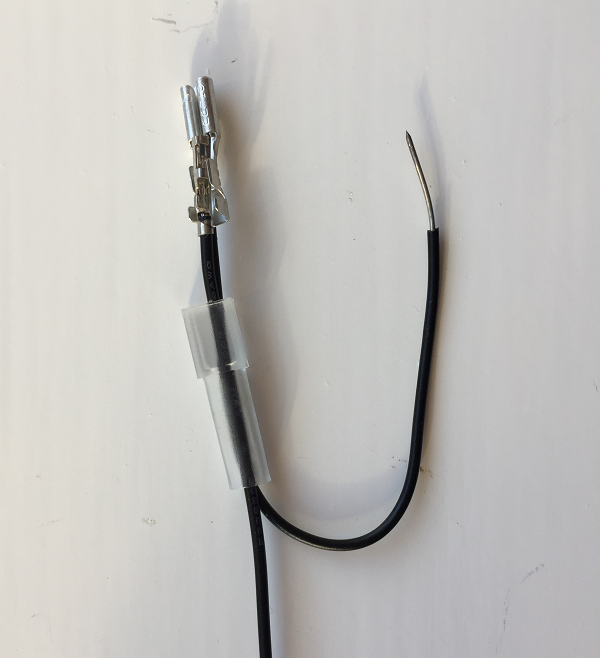
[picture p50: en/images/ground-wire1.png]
Black wire


+ Connect up the four remaining lengths of black wire to create a chain, crimping together a new wire with the exposed bare end of the previous wire. You will be left with one bare wire end as in the photograph below.

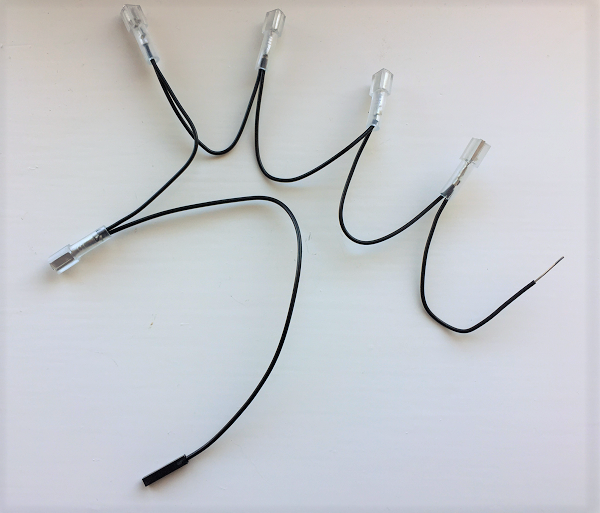
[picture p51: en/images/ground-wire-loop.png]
Black wire


+ For the final end, use pliers to fold the bare wire over to make it twice as thick before putting this wire alone inside a crimp and tightening up as before. You should end up with a chain containing six crimped ends and one black plastic jumper end.

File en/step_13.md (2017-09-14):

## Connect wires to the button terminals

First, you will connect your ground loop to the buttons.

+ Starting with the top button, take the crimped wire end furthest from the black plastic jumper lead. Slide the insulation boot down, hold the crimp between finger and thumb and push it all the way onto the button terminal. Once the crimp is firmly in place, slide the insulation boot back up.

+ Repeat to attach one of the black ground wire connections to each of the six buttons.

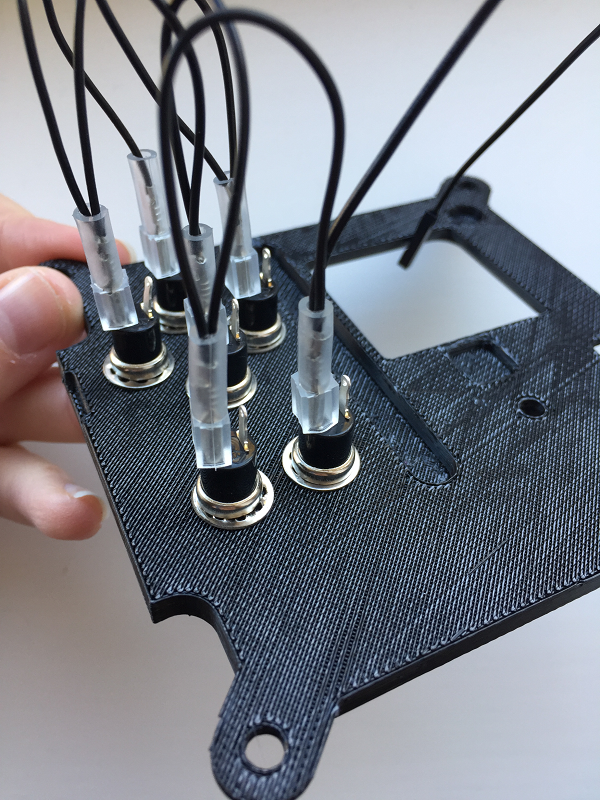
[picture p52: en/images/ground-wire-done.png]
Ground wire connected to buttons


+ Now take the coloured wires you made earlier and connect one crimped end to the spare terminal of each button, using exactly the same method.

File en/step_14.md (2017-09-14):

## Connect the buttons to the Raspberry Pi

+ Fit the middle section of the Astro Pi case onto the base. You should do this now, because the GPIO wires will prevent it from being fitted later.

Now you are going to wire the buttons to the free GPIO pins at the bottom of the header.

+ Turn the Astro Pi case so that the Ethernet and USB ports are at the bottom, and the GPIO pins are on the right of the Raspberry Pi.

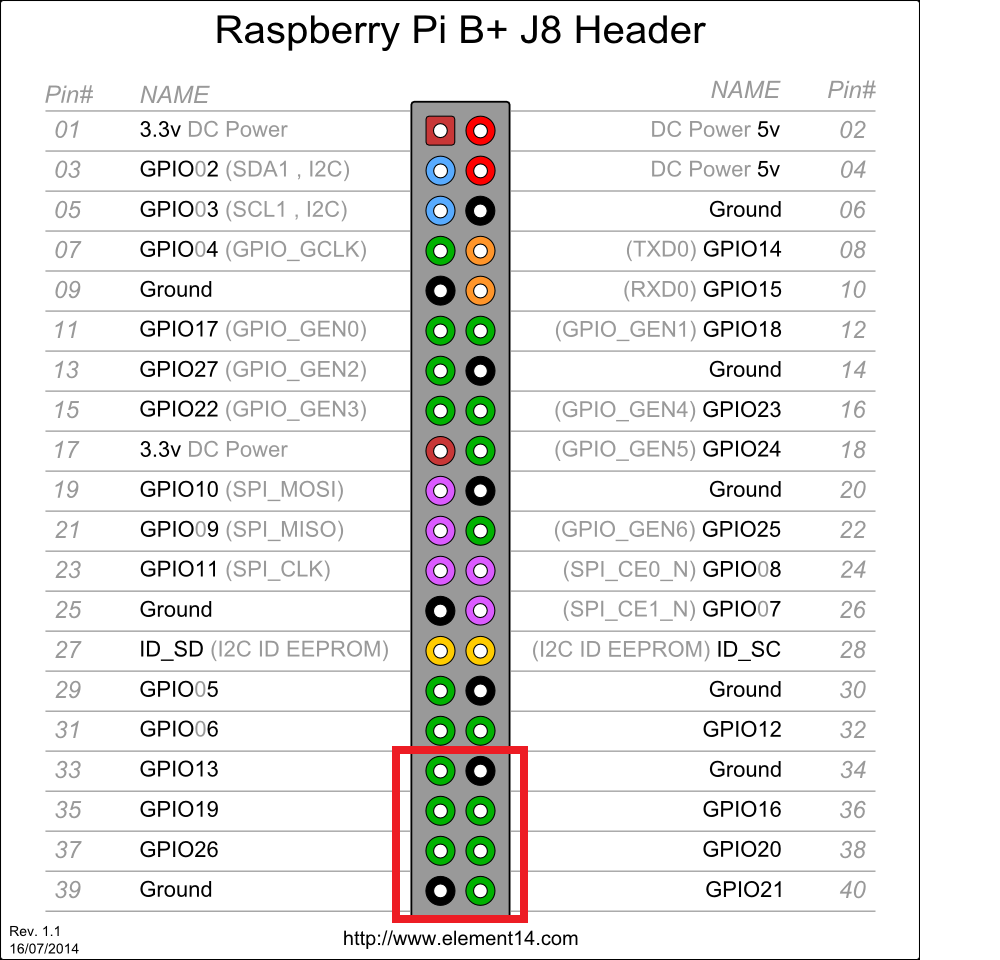
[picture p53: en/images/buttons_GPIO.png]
GPIO diagram


The pins marked in red are where you will wire up the buttons, with the bottom of the diagram being the pins closest to the USB ports.

+ Look at the **underside** of the lid, with the buttons on the left and the display hole on the right. Connect the coloured wire from each button to the corresponding pin below:

- Top four buttons
    - Top: **GPIO 26**
    - Bottom: **GPIO 13**
    - Left: **GPIO 19**
    - Right: **GPIO 20**
- Bottom pair of buttons
    - Left: **GPIO 21**
    - Right: **GPIO 16**

+ Finally, connect the ground wire to either pin 34 or 39 (labelled **Ground** on the GPIO diagram).

The lid will now be a bit awkward until we finish, but try to position it gently so it is not in the way.

The picture below shows one of the flight units that went into space. On the right, you can see the base of the RTC board with the connector pins for the buttons. If you look at the button contacts on the left, you'll see we used only one black ground wire going from button to button.

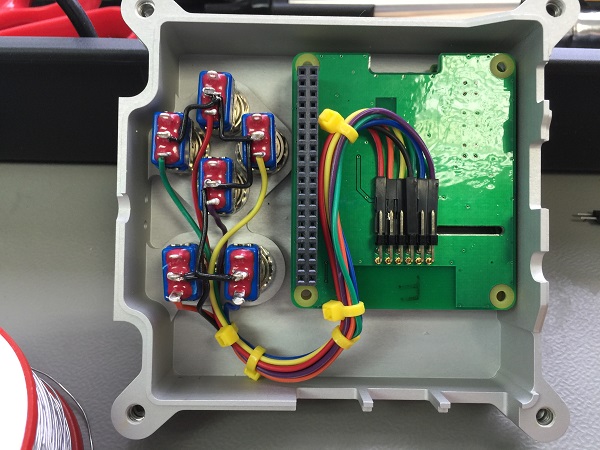
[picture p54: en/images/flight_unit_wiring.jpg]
Flight unit wiring


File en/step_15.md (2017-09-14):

## Install the Sense HAT

+ Remove the GPIO connector that comes with the Sense HAT. You can wiggle it from side to side, and it will come off without too much force.

+ The Sense HAT can then be attached onto the extended header. Note that the header pins should not protrude through the top of the Sense HAT. If they do, then the height is not correct.

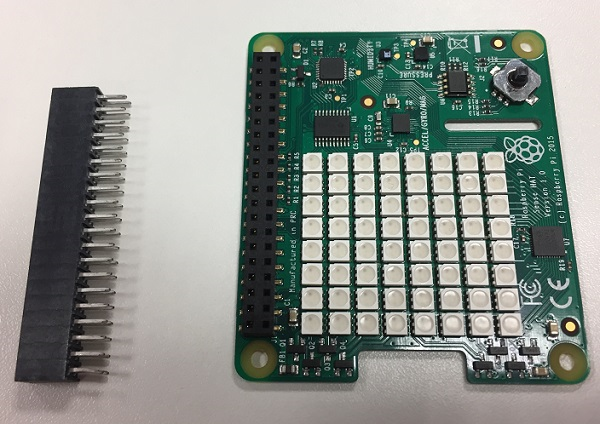
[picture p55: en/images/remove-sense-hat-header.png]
Remove the header from the Sense HAT


+ Finally, use the M2.5 cross-head screws to secure the Sense HAT to the stand-offs below.

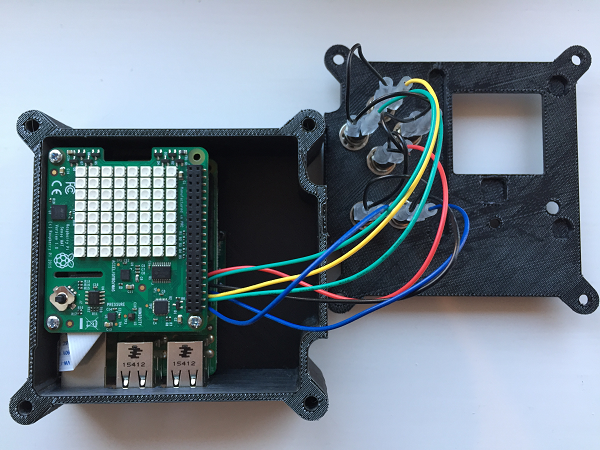
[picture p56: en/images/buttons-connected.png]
All buttons connected


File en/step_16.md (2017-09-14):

## Assemble the case

Once you're happy that the internals of the case are complete, you can proceed to the final assembly stage.

+ Take the lid and gently tuck the wires into the space on the right of the Pi as neatly as you can.

+ Place the lid on top of the case and align the heat sink on the bottom.

+ Take the black M4 threaded bolts, and insert one through each of the holes in the corners of the case. Inserting all four bolts at this stage will help to line everything up and make it easier to secure the case with the nuts.

+ Take one of the large hex nuts and use your index finger to place it against the bottom of the bolt. Push the bolt back up so that the nut is flush with the bottom of the case, and turn the head of the nut with your finger and thumb so that it catches the bolt thread. Tighten the nut with your fingers only.

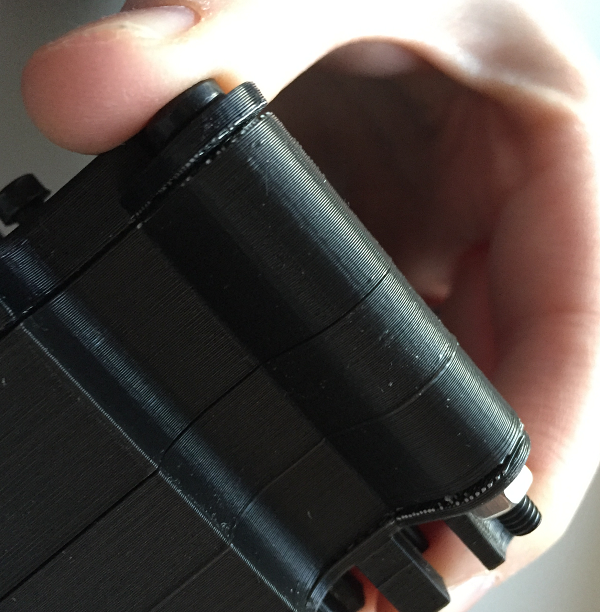
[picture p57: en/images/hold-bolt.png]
Hold the bolt


+ Once all four nuts are in place, you can do a final round of tightening with a screwdriver.

+ Your Astro Pi is almost complete — the last thing to do is install your 3D-printed joystick cap by pressing it onto the joystick. For this, the real flight units use a TrackPoint cap from a Lenovo ThinkPad laptop!

Install joystick

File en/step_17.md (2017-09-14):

## Test the buttons

+ Once you have assembled the Astro Pi, start it up with a monitor, keyboard, and mouse connected.

If you have the ESA-branded Astro Pi kit, the rainbow pattern on the LED matrix should disappear a few seconds after you turn the Astro Pi on, and the push-buttons should now type letters. You can test this in the terminal by running the test program at the bottom of this section.

If you don't have the ESA-branded Astro Pi kit, the rainbow pattern on the LED matrix will remain visible after you turn the Astro Pi on, and the buttons will not work yet.

You will need to download some files and change a few configuration settings, so make sure your Astro Pi is online.

+ Firstly, download the Device Tree overlay that maps the push-buttons to the corresponding keyboard keys. To do this, open a terminal window and enter these commands:

```bash
cd /boot/overlays
sudo wget https://github.com/raspberrypilearning/astro-pi-flight-case/raw/master/data/dtb/astropi-keys.dtbo --no-check-certificate
```

+ Type `ls` and check that the file `astropi-keys.dtbo` is now showing in the list of files.

+ Next, configure `config.txt` to load this overlay. Open the text file by typing:

```bash
sudo nano /boot/config.txt
```

+ Go to the bottom of the file and enter the two lines below:

```bash
dtoverlay=rpi-sense
dtoverlay=astropi-keys
```

+ Press `Ctrl` + `O`, and then `Enter` to save, followed by `Ctrl` + `X` to quit.

+ Now reboot the Astro Pi.

```bash
sudo reboot
```

Now let's download and run a Python test program to check everything is working. The test code uses [Pygame](http://pygame.org/wiki/tutorials){:target="_blank"}, which means you need to do this test on a directly connected monitor. It will not work via remote access.

+ Open a terminal window and enter these commands:

```bash
cd ~
wget https://github.com/raspberrypilearning/astro-pi-flight-case/raw/master/data/test_code/pygame_test.py --no-check-certificate
chmod +x pygame_test.py
./pygame_test.py
```

+ Wiggle the joystick and press all push-buttons. If everything is working, the joystick will give a direction indication, and the buttons will show the corresponding letter on the LED matrix. Press `Escape` to exit.

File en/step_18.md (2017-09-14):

## Challenge: improve your case

We've deliberately not shown a really polished gorgeous case, because we're hoping you'll go the extra mile and blow our socks off with yours! Show us your finished case by tweeting pictures of them to [@astro_pi](https://twitter.com/astro_pi){:target="_blank"} and [@raspberry_pi](https://twitter.com/Raspberry_Pi){:target="_blank"}.

Here are some further ideas for customising your case:

- Use metallic grey spray paint
- Use sandpaper to create the matte finish that the bead-blasted aluminium flight cases have
- Engrave decals into the case
- Use different colours of filament for each part

The STL files are released under the Creative Commons attribution [licence](http://creativecommons.org/licenses/by-sa/4.0/){:target="_blank"}, so you are welcome to modify them. Please note that GitHub has a great [STL viewer](https://github.com/blog/1465-stl-file-viewing){:target="_blank"}, as well as a [3D file diff](https://github.com/blog/1633-3d-file-diffs){:target="_blank"}, which could be useful for tracking your changes.

By far the greatest benefit of owning a replica Astro Pi flight unit is the ability to prototype and test code that could be run on the International Space Station. Head over to the [Astro Pi website](https://astro-pi.org/){:target="_blank"} now to get involved!

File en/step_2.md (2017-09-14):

## What you will need

### Hardware

+ Raspberry Pi
+ Raspberry Pi Camera Module or NoIR Camera Module
+ Sense HAT
+ [Astro Pi components kit](http://cpc.farnell.com/ucreate/uc-apk-comp1/astro-pi-component-kit-budget/dp/SC14158){:target="_blank"}

### Additional requirements

+ Access to a 3D printer. Many schools now have their own, but if your school doesn’t, you might be able to find one at your local [hackspace](http://www.hackspace.org.uk/){:target="_blank"}. You can also find local 3D printing services through the [3D Hubs website](https://www.3dhubs.com/){:target="_blank"}.

You’re also going to need the following tools:

+ Small cross-head screwdriver
+ Small pair of pliers
+ Craft knife or scalpel
+ Sandpaper
+ Tape
+ Wire strippers
+ Wire cutters

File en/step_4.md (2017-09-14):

## Print each part

**It is important that you observe the correct safety procedures specified in the data sheet for your specific 3D printer.**

Potential hazards include:

- Hot surfaces and thermoplastics (print head block and lamp)
- Ultraviolet radiation (lamp)
- High voltage (lamp connector, electric outlet)
- Moving parts (printing assembly)

The 3D printer we used for the black parts shown was an [Up Plus 2](https://www.3dhubs.com/3d-printers/up-plus-2){:target="_blank"}, called the Afinia H480 in the US, using ABS filament. There are many different 3D printer models, and we cannot possibly provide instructions for them all. We can only provide rough guidance here, and you'll need to figure out the rest on your own.

Here are some top tips:

- Spend some time making sure your printer is properly calibrated and tested
- [PLA](https://en.wikipedia.org/wiki/Polylactic_acid){:target="_blank"} is more reliable and nicer to print with than [ABS](https://en.wikipedia.org/wiki/Acrylonitrile_butadiene_styrene){:target="_blank"}
- A [Zebra](http://www.printinz.com/zebra-plates/){:target="_blank"} or [Buildtak](http://www.buildtak.eu/){:target="_blank"} plate provides a great surface to print on and doesn't require any extra adhesive
- If your printer has a Z probe sensor, this will help compensate for the bed not being perfectly level — if you have one, ensure it's working correctly

In order to get a nice finish we recommend you print on a high detail setting; this is usually a number specified in [microns](https://en.wikipedia.org/wiki/Micrometre){:target="_blank"} in the 3D printer software. The lower this number is, the more precise the model will be. Please also be aware that precise prints take longer and, for the models you're going to make, each piece can take up to **four** hours to complete. Make sure you have enough filament.

The STL files should have the models in the right orientation by default, but please make sure you print in the orientations shown below in order to minimise scaffolding and rafting.

### Heat sink

Anti warp heat sink raw print

### Base

Anti warp base raw print

### Middle

Anti warp middle raw print

### Lid

Anti warp lid raw print

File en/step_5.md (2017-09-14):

## Remove the scaffolding

In order to keep the model structurally sound while printing, your 3D printer will create what's called scaffolding and rafting to prevent the hot thermoplastics from bending or sagging. Leave the print to cool right down to room temperature before you touch it.

### Heat sink

You should be able to remove the scaffolding on the heat sink using just your hands; this part may bend slightly, so don't be too rough while you are removing the unwanted material.

Peel off the heat sink scaffolding

You may choose to not print this part because it's not essential to the rest of the case, and because it's made of plastic it **will not** work as a heat sink. We've included it, though, so that you can achieve the iconic look and feel of the Astro Pi flight case.

### Base

Like the heat sinkt, the base scaffolding should come away easily.

Peel off the base scaffolding

If you break off some scaffolding by accident, carefully prise up the remaining scaffolding using a scalpel and then continue peeling it off with your fingers.

If the scaffolding breaks

Don't worry if you scuff the surface with the scalpel, as the rough side of the print will not be visible when the case is assembled.

Don't forget to clear the material around the SD card slot; this can be done easily using pliers.

Clear the SD card slot

### Middle

Again, the scaffolding should come away easily if you peel it with your fingers.

Peel off the middle scaffolding

### Lid

Peel off the bottom layer of scaffolding as before.

When you first peel off the lid

However, this part has a few sunken holes on the underside that must also be cleared of material. These are present to prevent the lid from striking the Raspberry Pi hardware when it is installed in the case. You'll need a scalpel or craft knife to dig into it.

Use a scalpel to lift the scaffold

Once you've managed to lift some of it, use a small pair of pliers to remove the rest of the material. The areas marked with a red star in the image below need the same treatment.

Stars show which bits need to be removed

When you're done, it should look like this:

Cleaned up lid

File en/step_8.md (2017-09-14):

## Install the camera

When you're happy with the 3D-printed parts, you can proceed to the hardware installation.

Getting the camera into the case can be a little tricky, but here is how we did it for the flight units:

+ Firstly, lift the two tabs on either side of the Camera Module to disconnect the ribbon cable from the camera.

Then fold the ribbon. These folds allow the camera cable to come up the side of the Raspberry Pi with enough flex to insert into the CSI camera port (see further down).

+ Lay the ribbon out with the writing face up and the visible connectors on the left. At 1cm along the ribbon, fold the ribbon downwards.

  Fold down at 1cm

+ Now measure 4cm from the top of the ribbon and fold the ribbon to the right.

  Fold 4cm right

+ Finally, measuring 4cm from the bottom-left corner, fold the ribbon upwards.

  Fold 1cm

+ Tape the ribbon on the bottom to prevent it from unfurling. We have used Kapton tape, but any kind of tape will work fine.

  Camera with tape

You don't need to get this perfect for it to work, but try to do it as precisely as you can.

+ Reconnect the **Cam** end of the ribbon cable to the Camera Module. Make sure that the tin connectors are facing the front and the blue tab is on the back.

+ Before proceeding, line the Camera Module up with the support pillar pilot holes and have a look through the aperture in the base to check the alignment of the lens. The lens block of the Camera Module is actually glued in position at the factory, and therefore its alignment can vary slightly from camera to camera. If you find you've got an alignment issue, you should be able to manipulate the lens block between finger and thumb before you install it into the case permanently.

+ When you're happy, use the small black M2 cross-head screws to install the Camera Module. The screws will cut their own thread in the support pillar pilot holes, but after a few turns you'll probably need a small screwdriver to continue.

Screw in the camera

Stop turning as soon as the head of the screw touches the Camera Module; if you tighten the screw too much, it can cause the support pillar to split horizontally along the grain of the print. Furthermore, try to avoid removing and re-threading the screws, as doing so will cut a new thread and, if done repeatedly, will erode the inside of the support pillar so that the screws will not hold.

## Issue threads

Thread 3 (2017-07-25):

3d-printed/images missing

raspberrypilearningbot, 2017-07-25:
/learning was expecting a file or directory at 3d-printed/images

Closed 2017-07-31.

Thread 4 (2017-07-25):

3d-printed/images missing

raspberrypilearningbot, 2017-07-25:
/learning was expecting a file or directory at 3d-printed/images

Closed 2017-07-31.

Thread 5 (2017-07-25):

3d-printed/images missing

raspberrypilearningbot, 2017-07-25:
/learning was expecting a file or directory at 3d-printed/images

Closed 2017-07-31.

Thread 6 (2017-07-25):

3d-printed/images missing

raspberrypilearningbot, 2017-07-25:
/learning was expecting a file or directory at 3d-printed/images

Closed 2017-07-31.

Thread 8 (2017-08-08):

STL links now broken in worksheet

davidhoness, 2017-08-08:
- Anti-warp base for Pi 3
- Middle
- Anti-warp middle

davidhoness, 2017-08-08:
- Anti-warp base for Pi 3
- Middle
- Anti-warp middle

Closed 2017-08-08.

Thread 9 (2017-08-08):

Please read if changing path to STL files

davidhoness, 2017-08-08:
There is a short URL (http://rpf.io/apstl) pointing to the STL folder which is featured in the Astro Pi 3D printed assembly [video](https://www.youtube.com/watch?v=zmJOA6WzfZw).

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

If the path to the 3D print STL files is ever changed can the short URL be updated in http://rpf.io/admin/ please? I have updated it on 08/08/17.

Many thanks

lawsie, 2017-08-08:
@MarcScott

MarcScott, 2018-02-15:
Noted

Closed 2018-02-15.

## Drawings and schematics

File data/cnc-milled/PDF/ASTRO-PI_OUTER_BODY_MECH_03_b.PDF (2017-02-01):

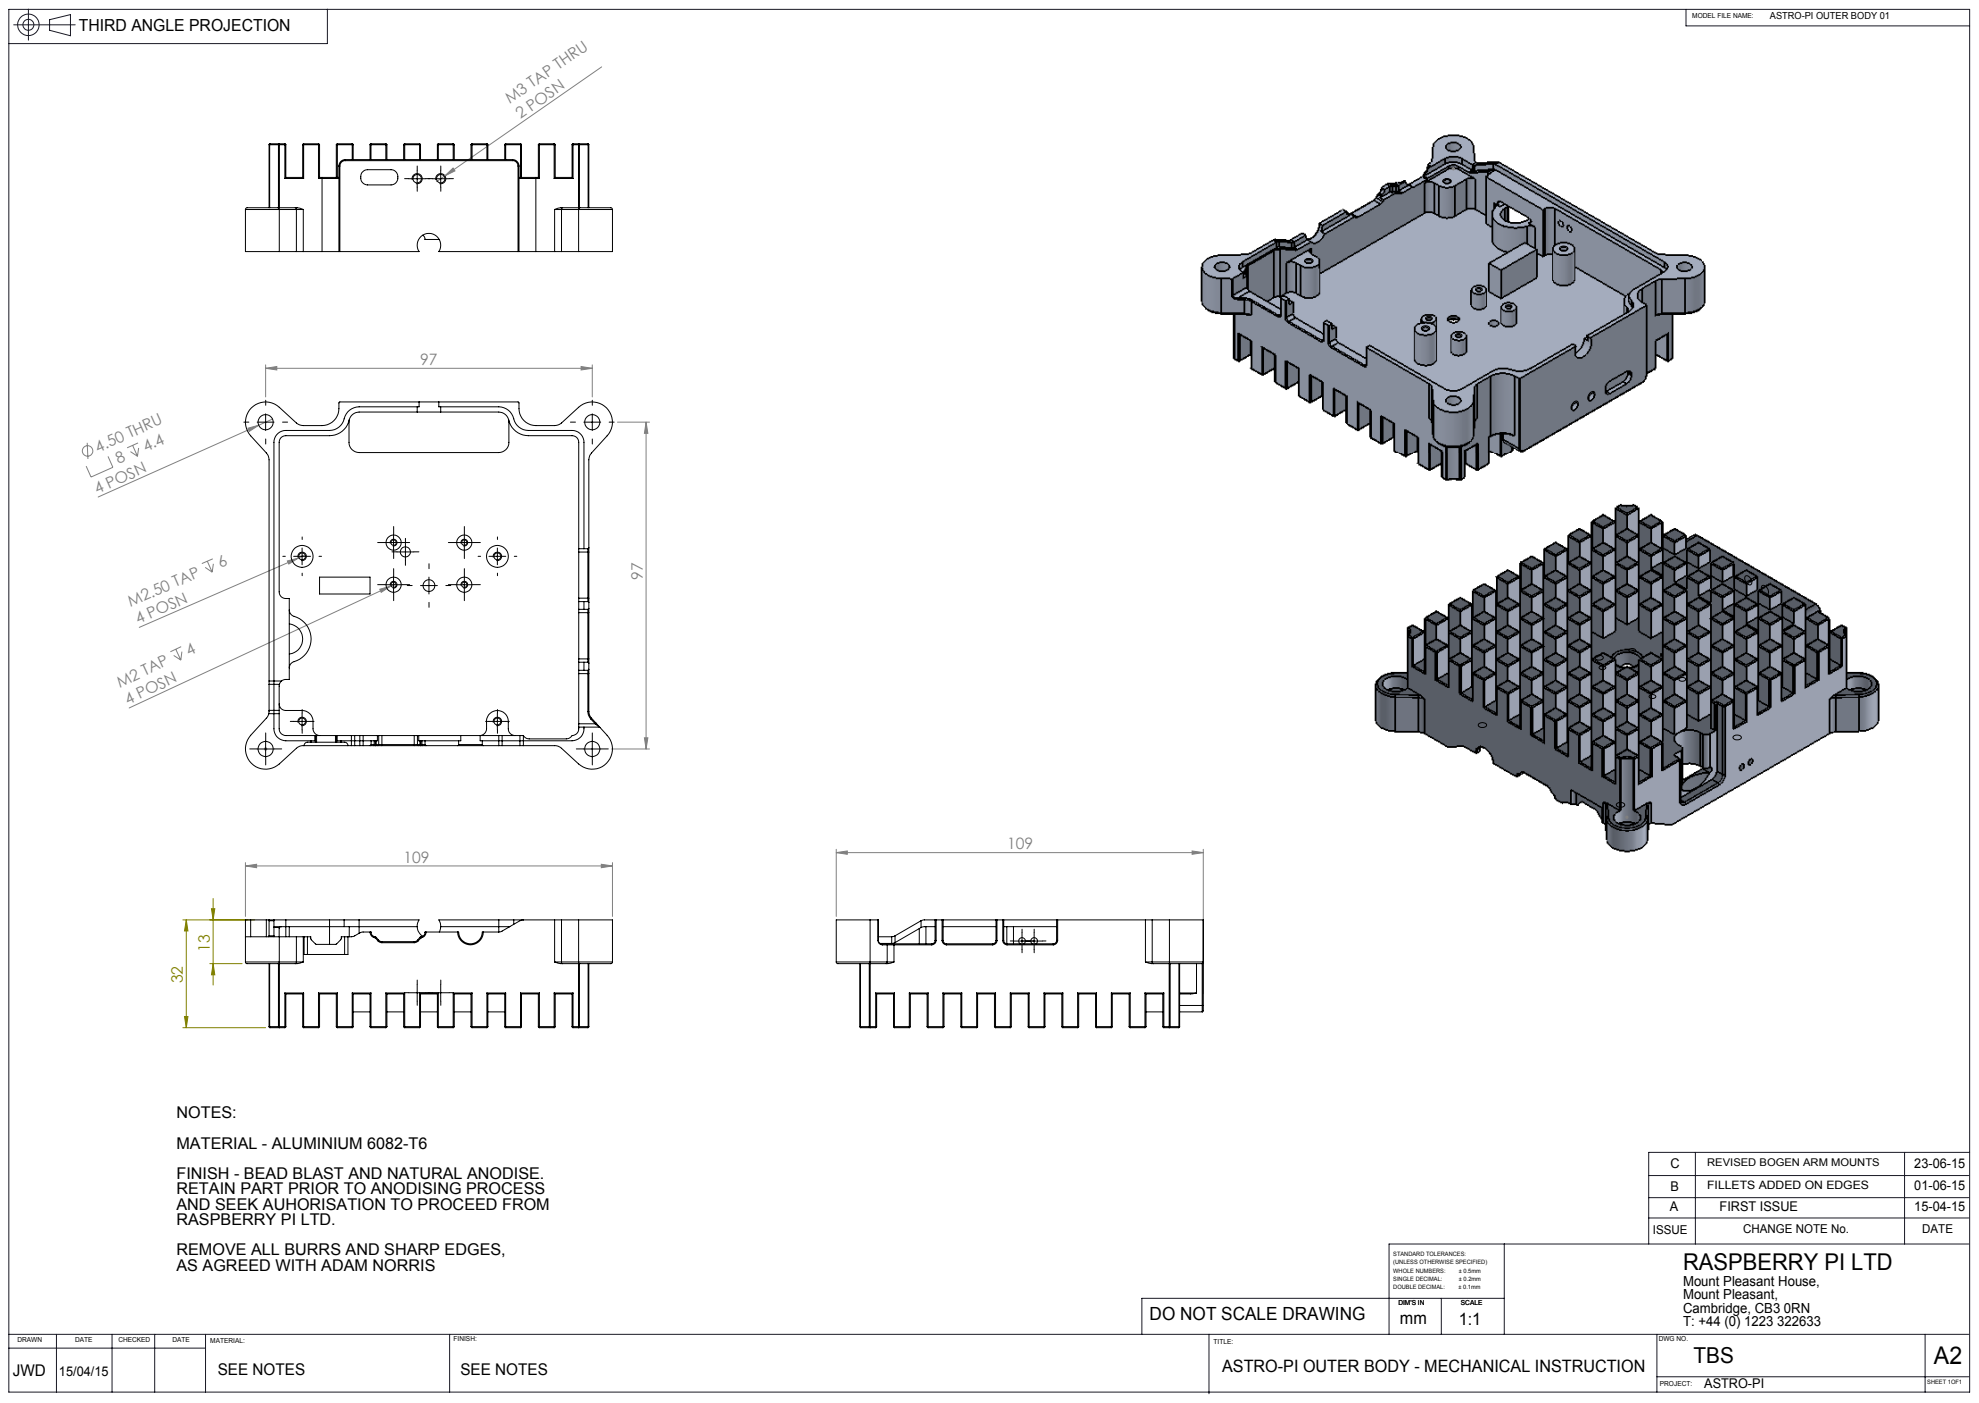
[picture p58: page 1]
M2.50 TAP 6; 4 POSN; M2 TAP 4 4 POSN; 4.50 THRU 8 4.4 4 POSN; M3 TAP THRU; 2 POSN; SHEET 1OF1; DOUBLE DECIMAL:; SINGLE DECIMAL:; WHOLE NUMBERS:; SEE NOTES; TBS; DIM'S IN; SCALE; ISSUE; CHANGE NOTE No.; DATE; TITLE:; DWG NO.; FILLETS ADDED ON EDGES; REVISED BOGEN ARM MOUNTS

ASTRO-PI OUTER BODY 01

THIRD ANGLE PROJECTION

MODEL FILE NAME:

NOTES:
MATERIAL - ALUMINIUM 6082-T6
FINISH - BEAD BLAST AND NATURAL ANODISE.
RETAIN PART PRIOR TO ANODISING PROCESS
AND SEEK AUHORISATION TO PROCEED FROM
RASPBERRY PI LTD.
REMOVE ALL BURRS AND SHARP EDGES,
AS AGREED WITH ADAM NORRIS

FIRST ISSUE
RASPBERRY PI LTD
Mount Pleasant House,
Mount Pleasant,
Cambridge, CB3 0RN

STANDARD TOLERANCES:
(UNLESS OTHERWISE SPECIFIED)

DO NOT SCALE DRAWING

ASTRO-PI OUTER BODY - MECHANICAL INSTRUCTION

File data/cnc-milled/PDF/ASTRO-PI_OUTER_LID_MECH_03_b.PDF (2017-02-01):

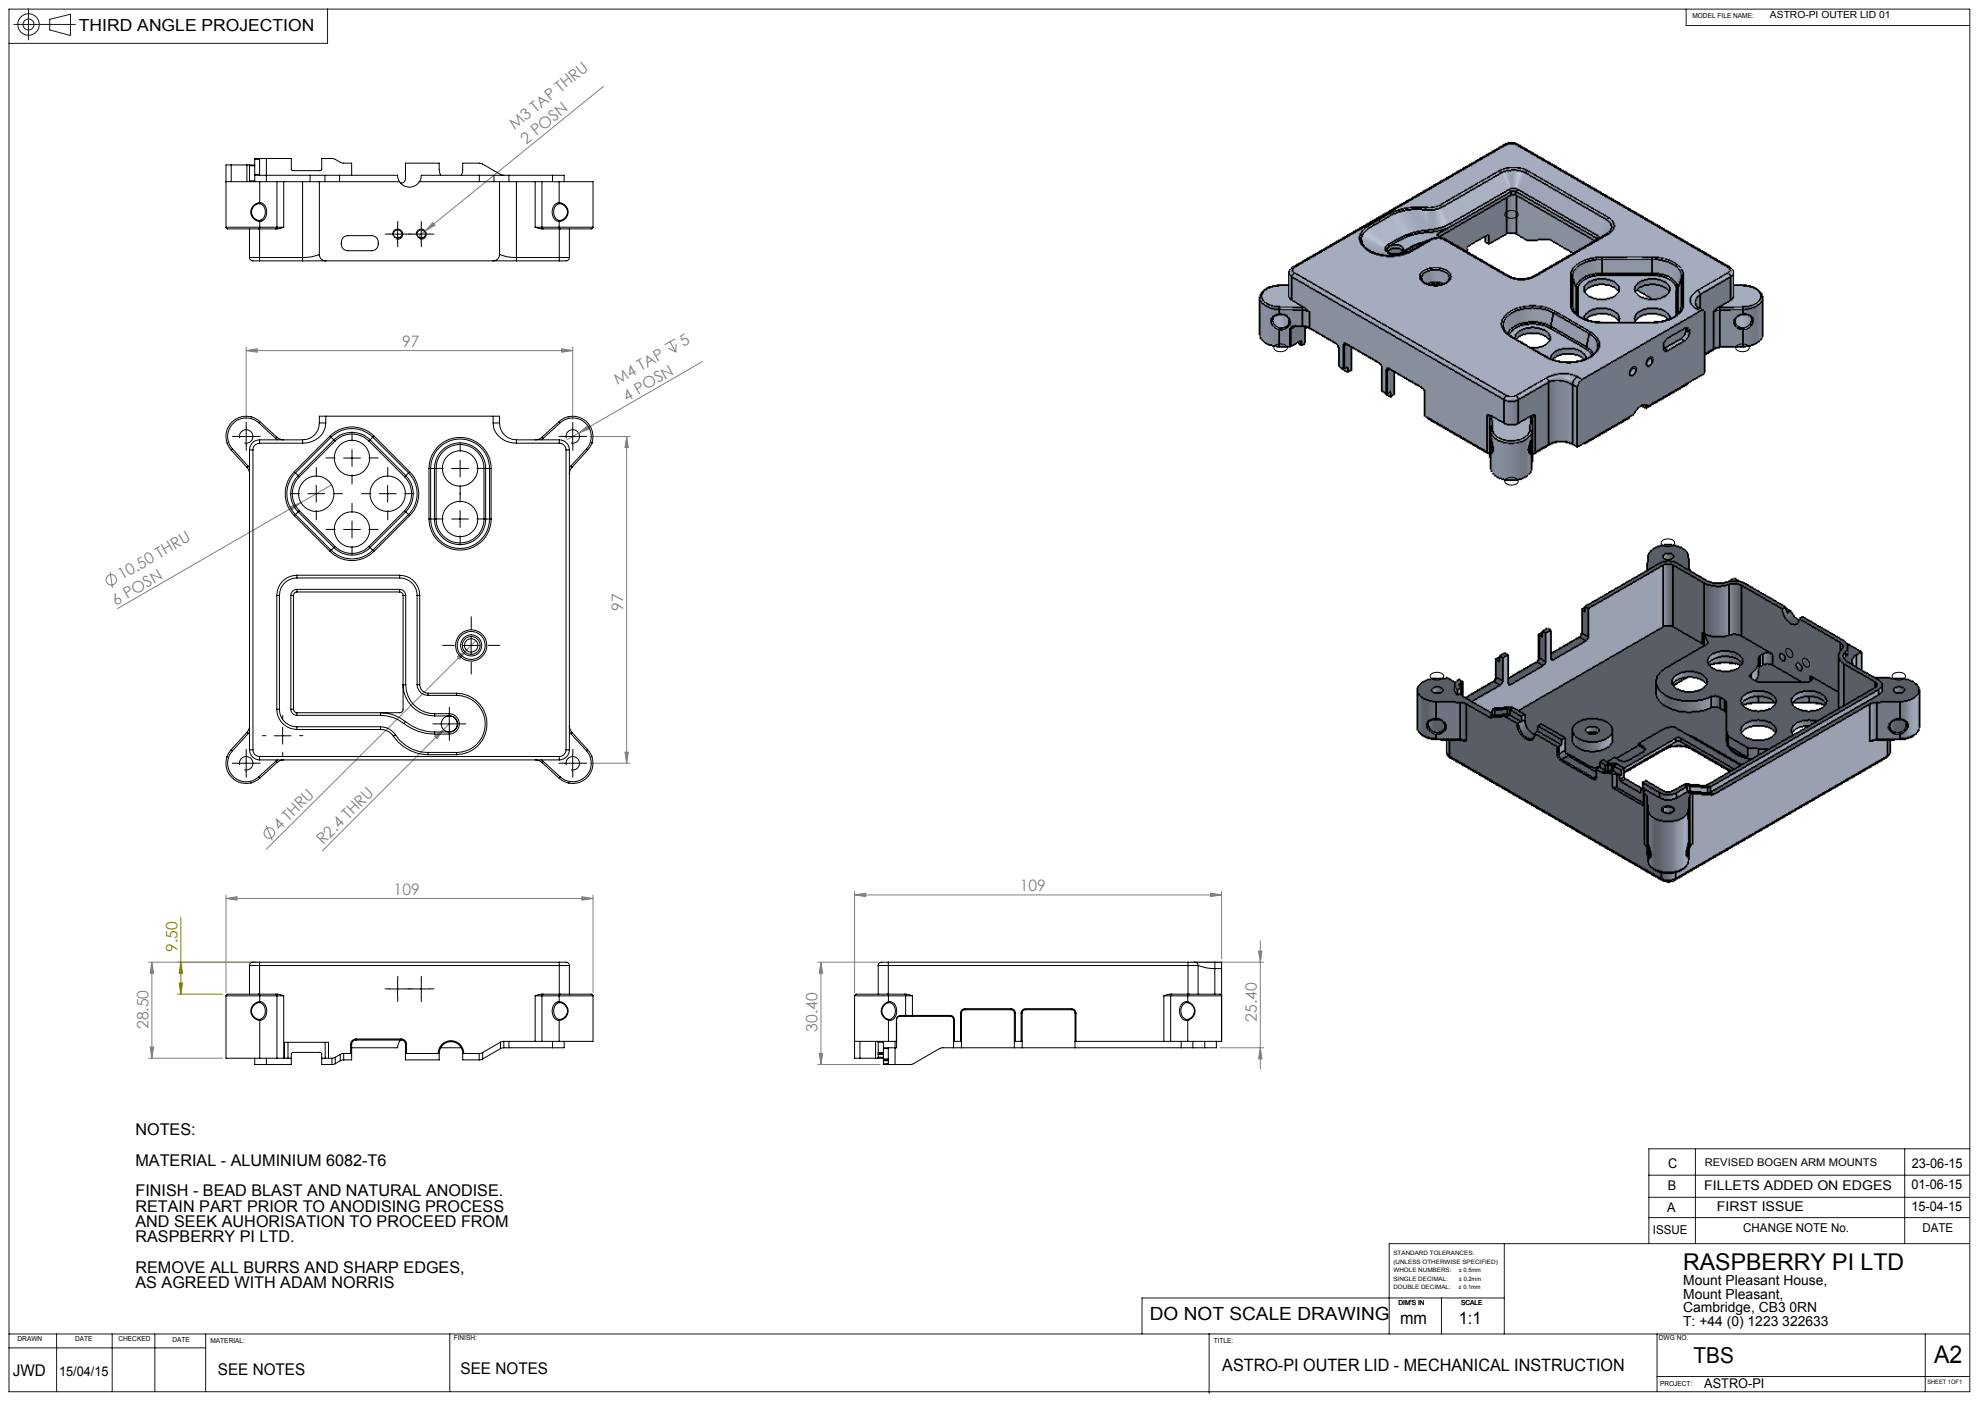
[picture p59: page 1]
10.50 THRU; 6 POSN; M4 TAP 4 POSN; 4 THRU; R2.4 THRU; M3 TAP THRU; 2 POSN; DIM'S IN; SCALE; ISSUE; CHANGE NOTE No.; DATE; TBS SEE NOTES; SEE NOTES; SINGLE DECIMAL:; SHEET 1OF1; FIRST ISSUE; REVISED BOGEN ARM MOUNTS

THIRD ANGLE PROJECTION

MODEL FILE NAME:

ASTRO-PI OUTER LID 01

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

FILLETS ADDED ON EDGES
RASPBERRY PI LTD
Mount Pleasant House,
Mount Pleasant,
Cambridge, CB3 0RN

STANDARD TOLERANCES:
(UNLESS OTHERWISE SPECIFIED)
WHOLE NUMBERS: ± 0.5mm
DOUBLE DECIMAL: ± 0.1mm

DO NOT SCALE DRAWING

A2 DWG NO. TITLE:
ASTRO-PI OUTER LID - MECHANICAL INSTRUCTION

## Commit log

2016-11-24 Initialise all
    [hardware.yml]
2016-11-24 new cad files for ESA
    [Astro_Pi_Base_Pi1_or_2.stl, Astro_Pi_Base_Pi1_or_2_warp.stl, Astro_Pi_Base_Pi3.stl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]
2016-11-24 Link to STL files
2016-11-24 Add new images of raw prints
2016-11-24 Update downloads STL
2016-11-24 More STL link updates
2016-11-24 Peeling off heat sink
2016-11-24 Change order of worksheet 1 to 3d print first to match the video
2016-11-24 Folding camera added
2016-11-24 Add camera install
2016-11-24 Screw in the pi
2016-11-25 Change images with 3 standoffs
2016-11-25 Add button instructions
2016-11-25 Button wire description
2016-11-25 Uploading missing wire crimp image
2016-11-25 Add ground wire description and pics
2016-11-25 Connected buttons
2016-11-25 Finished case
2016-11-28 source for dtbo, in case it needs changing some day
2016-11-30 copy edit
    Added hyphen in "3D-Printed" as it is an adjectival form
2016-11-30 Copy edit
    [hardware.yml]
2016-11-30 Capitalisation/minor corrections
    Note to copyeditors: when referring to the Pi camera, it should *always* be capitalised as Camera Module, as per the [style guide](https://github.com/raspberrypilearning/style-guide). Please also pay attention to trademarks; the button on a ThinkPad is a TrackPoint, not 'track point'.
2016-12-02 fix broken STL links
2016-12-02 binary version
    [Astro_Pi_Joystick.stl]
2016-12-05 add joystick printing advice
2017-02-01 Organising files
    [Astro_Pi_Base_Pi1_or_2.stl, Astro_Pi_Base_Pi1_or_2_warp.stl, Astro_Pi_Base_Pi3.stl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]
2017-02-01 STEP and Parasolid
    [Astro_Pi_2.0_Enclosure_3D_PRINT_SECTION_1 V1.STEP, Astro_Pi_2.0_Enclosure_3D_PRINT_SECTION_1 V1.x_t, Astro_Pi_2.0_Enclosure_3D_PRINT_SECTION_2 V1a.STEP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]
2017-02-01 flight CAD
    [Astro_Pi_Enclosure_Body_EXPORTED_STL_050116.STL, Astro_Pi_Enclosure_Lid_EXPORTED_STL_050116a.STL]
2017-07-31 update for slash learning
    [Astro_Pi_2.0_Enclosure_3D_PRINT_SECTION_1 V1.STEP, Astro_Pi_2.0_Enclosure_3D_PRINT_SECTION_1 V1.x_t, Astro_Pi_2.0_Enclosure_3D_PRINT_SECTION_2 V1a.STEP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]
2017-08-01 fix for slash-learning
    [Astro_Pi_2.0_Enclosure_3D_PRINT_SECTION_1 V1.STEP, Astro_Pi_2.0_Enclosure_3D_PRINT_SECTION_1 V1.x_t, Astro_Pi_2.0_Enclosure_3D_PRINT_SECTION_2 V1a.STEP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]
2017-08-08 Fix broken STL links
    Fixes #8
